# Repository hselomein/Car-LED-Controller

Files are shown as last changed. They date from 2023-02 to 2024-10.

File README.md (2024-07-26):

# Car-LED-Controller

Credits:
  - Corey Davis created the project and put together the prototypes.
  - Yves Avady wrote the code for this project.

This project controls an addressable LED Strip and LED matrix using the light inputs from a car electrical system.

With this project, we are taking an esp32 microcontroller and making an LED controller for the strip. 
The LED strip is a 12v WS2811 with 120 LEDs per meter

LED Strip Actions:
- Startup is a night rider style sweep 3 times until it is a solid white bar
- DRL Modes will control the LED strip brightness.

-  When DRLs are in Daytime Running Light Mode strip will be at full brightness
-  When DRLs are used as parking lights, the strip will be dimmed to a lower brightness
  
- Horn usage makes the lights turn dark amber to represent "Angry Mode"
- Indicators will show using a single chasing pattern that stays on for as long as the voltage is applied. This is to match the blink of the indicator circuit
- When hazard lights are on there will be a chasing pattern starting from the middle and ending at the ends
- There will be a button to cycle between Normal, Uber, and Lyft Modes
- Uber Mode, the led strip will be a Seafoam Greem color
- LYFT Mode, the led strip will be Magenta
There will be a physical switch installed to disable the light for law enforcement and/or vehicle inspection purposes

There are 5 voltage reading inputs 

  - DRL Left Sensing, 
  - DRL right Sensing,
  - Horn Sensing,
  - Left Indicator,
  - Right Indicator

At powerup LED strip will sweep 3 times each pass leaving the light on brighter until filled.
It'll stay filled white unless another mode is selected or an action happens

2 LED Matrices will be attached to the front and back of the vehicle and show 1 of 3 screens
  - Off or Blank for normal driving mode
  - Uber Mode: Shows Uber logo
  - Lyft Mode: Shows Lyft Logo

Actions:
DRL is in DRL Mode light will be at full brightness
DRL is in parking light mode and will be at half-brightness
When not in Uber or Lyft mode, the LED Matrix will be blank or off
Horn is pressed LED Strip will turn orange for the duration of the press
UBER Mode will turn the lights Cyan and the LED Matrix will show the Uber logo
Lyft Mide will turn the lights Magenta and the LED Matrix will show the Lyft Logo
Angry Mode will be some orangy red color, cant be RED as that is illegal in the front
The left indicator will show a chasing pattern, starting in the center and moving to the left side of the strip
The right indicator will show a chasing pattern, starting in the center and moving to the right side of the strip
Vehicle inspection mode, which will disable the lights, physical switch

There is a parts list so you can build this as well.

How to use with Platform-io IDE:
- You will need the Platformio-ide extension installed in VSCODE to compile the code
The src folder is where the code you want to compile and upload code to the ESP32
The main program code is in the file "main.cpp".

How to use with Arduino IDE
- The Arduino project files are located in the ArduinoIDE folder. This part is not complete still porting the code

This program is modular. You can enable or disable specific features by setting directives to true or false.

Build Configuration Options - This program is modular in the sense that you can have everything (LED Strip, LED Matrix) work or just cartain parts.  
See the Build Configuration Options to enable or disable certain features.

Examples:  
//Build Configuration Options  
  #define DEBUG false       //Enable serial output for debug, change to "false" to disable  
  #define SCREENTEST false  //To enable the boot up screen test, change to "true", to disable change to "false"  
  #define LED_MATRIX true   //Set to "true" if you want to use a 64x64 LED Matrix, "false" to disable  
  #define LED_STRIP true    //Set to "true" if you want to use the led strip, "false" to disable  
  #define NUM_MODES 2       //How many modes will the mode button handle (2 for Uber and Lyft signs)  

Code Notes:
- Car_LED_Controller-LED_Matrix_64x64.ino - this is the program for the 64x64 P2 LED Matrix for the Arduino ide, this still needs to be completed
- Part List - this is the shopping list of parts for this project

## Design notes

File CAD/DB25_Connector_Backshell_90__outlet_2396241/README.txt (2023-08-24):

DB25 Connector Backshell 90° outlet by PeterBrit on Thingiverse: https://www.thingiverse.com/thing:2396241

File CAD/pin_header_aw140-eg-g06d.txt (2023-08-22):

"Symbol";"Value";"Unit";
"TraceParts.PartNumber";"10-15062010-090510";"";
"REFERENCE";"AW140-EG-G06D";"";
"TraceParts.PartTitle";"Pin header, pitch 2.54mm, straight, single row, 6 contacts, plating : Gold flash, pin length = 11,2mm ( A=5,66; B=3,00)";"";
"TraceParts.InstanceId";"10-15062010-0905107AUE0LFKUDNPOKZ3LGYJF4ZHA";"";
"SUPPLIER";"ASSMANN WSW components";"";
"DESIGN";"Pin header, pitch 2.54mm, straight, single row, 6 contacts, plating : Gold flash, pin length = 11,2mm ( A=5,66; B=3,00)";"";
"TraceParts.PartVersion";"1.2.7";"";
"TraceParts.PartLanguage";"en";"";

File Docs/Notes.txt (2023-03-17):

Arduino LED Controller

Power: 0v - 15v 
What it powers, Arduino, 3x 5v buck converters, 1 white 60" led strip  
Input1: 1 voltage divier circuit that divides automotive level voltage 11 times: 1-1Mohm and 1-100kohm resistors
Expected input ranges: 0v to 15v
Expected divided voltage: 0v ,12v = 1.091v ,15v = 1.364v
Input2: 1 voltage divier circuit that divides automotive level voltage 11 times: 1-1Mohm and 1-100kohm resistors
Expected input ranges: 0v to 15v
Expected divided voltage: 0v ,12v = 1.091v ,15v = 1.364v

voltage divider
DRL -> 1M -> sense pin -> 47k -> ground

 pseudo code
Buf = 1 //+-1v
Div = 50 / 1000 //divider value
LBL = 2 //2v low beam
DRL = 12 //12v DRL 
Brightness = in / Div
If abs(brightness - LBL) < Buf then lowBeam=true
Also, to set led brightness
LEDv = brightness * 256 / 12
If LEDv > 256 then LEDv =256
If LEDv < 0 then LEDv =0c ch

Arduino setup
Pins to device mapping
D2 => In1 Relay
D3 => In2 Relay
A2 => DRL Sense
A3 => PK_L Sense
A4 => Hn Sense
A5 => HiBm Sense
# of LEDs in strip 30 effective 90 individual pixels, WS2811 controller 

ESP32 Notes:
https://www.electronicshub.org/esp32-pinout/

Pins required:
4 analog pins for input
1 ditigal pin for input
8 digital pins for output
2 power pins

Reserved pins:
2-4 input only pins
12 bootstrap pin
14-17 power and ground
27,28 uart0 rx/tx 
6-11 do not use on 36 or 38 pin verson, in use for flash,  - these are not exposed on pu 30pin version
33, 39 connected to hall sensor

Planned pinout:
2 DRL Sense GPIO36
3 PK_L Sense GPIO39
4 Hn Sense GPIO34
5 HiBm Sense GPIO35

21 LCD Data (SDA)
22 LCD Clock (SCL)

27 Relay1
14 Relay2

30 Mode Selection Button Output GPIO23
29 Reserved
26 LED Strip DAta GPIO21

HArdware List
ESP32-WROOM-32
bidrectional logic level converter
20A Buck converter
40in led strip

Car Tested Voltages
Car Off, DRL in parking light mode on : 1.9v
Car On, DRL in parking light mode on : 2.0v
Car on, DRL mode on : 14.8v

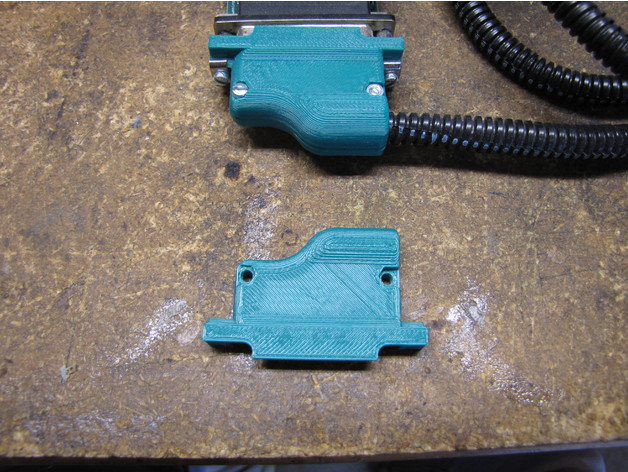
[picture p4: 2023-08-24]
CAD/DB25_Connector_Backshell_90__outlet_2396241/images/e1f9b99bbdfb767f7688bc1128a824b8.JPG

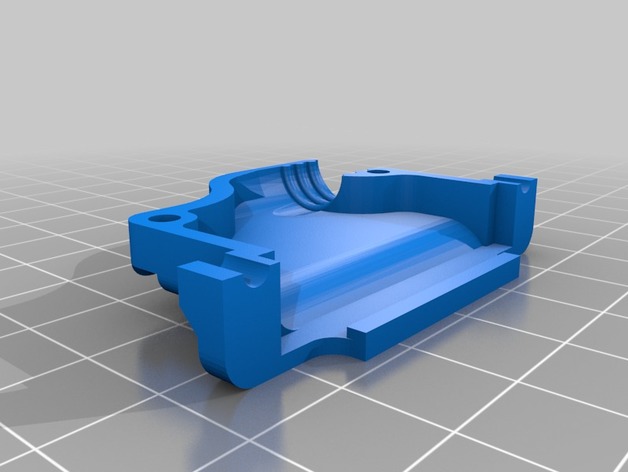
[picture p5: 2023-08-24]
CAD/DB25_Connector_Backshell_90__outlet_2396241/images/DB25_backshell_a.jpg

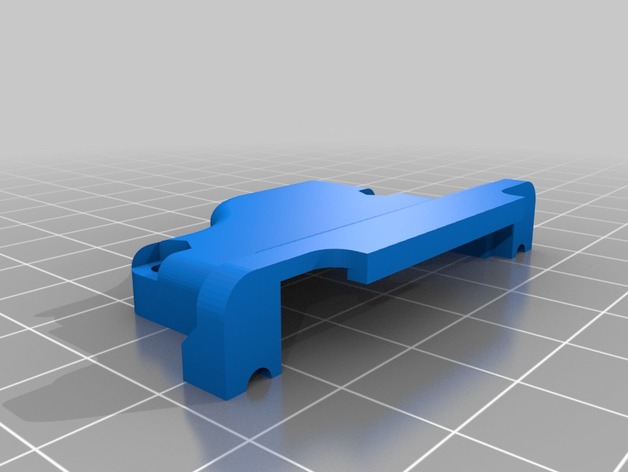
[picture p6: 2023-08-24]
CAD/DB25_Connector_Backshell_90__outlet_2396241/images/DB25_backshell_b.jpg

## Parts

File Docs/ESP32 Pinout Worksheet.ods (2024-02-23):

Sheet: ESP32-WROOM-32_30PIN
Label | GPIO | Safe to use? | Reason | Device Assigned | Need to assign to alternate location | Notes
D0 | 0 | Caution | must be HIGH during boot and LOW for programming
TX0 | 1 | Not Recondmended | Tx pin, used for flashing and debugging
D2 | 2 | Caution | must be LOW during boot and also connected to the on-board LED | LED Strip
RX0 | 3 | Not Recondmended | Rx pin, used for flashing and debugging
D4 | 4 | Yes |  | LED Matrix
D5 | 5 | Caution | must be HIGH during boot | LED Matrix
D12 | 12 | Caution | must be LOW during boot | LED Matrix
D13 | 13 | Yes |  | LED Matrix
D14 | 14 | Yes |  | LED Matrix
D15 | 15 | Caution | must be HIGH during boot, prevents startup log if pulled LOW | LED Matrix
RX2 | 16 | Yes |  | LED Matrix
TX2 | 17 | Yes |  | LED Matrix
D18 | 18 | Yes |  | Relay
D19 | 19 | Yes |  | Relay
D21 | 21 | Yes |  | Character LCD
D22 | 22 | Yes |  | LED Matrix |  | To declare other pins for i2c communication, add this to the code in the setup, Wire.begin(I2C_SDA, I2C_SCL); https://microcontrollerslab.com/esp32-i2c-communication-tutorial-arduino-ide/
D23 | 23 | Yes |  | LED Matrix
D25 | 25 | Yes |  | LED Matrix
D26 | 26 | Yes |  | LED Matrix
D27 | 27 | Yes |  | LED Matrix
D32 | 32 | Yes |  | LED Matrix
D33 | 33 | Yes |  | Character LCD
D34 | 34 | Caution | Input only GPIO, cannot be configured as output, No Internal pull up /down resistors | DRL Sense
D35 | 35 | Caution | Input only GPIO, cannot be configured as output, No Internal pull up /down resistors | Horn Sense
VP | 36 | Caution | Input only GPIO, cannot be configured as output, No Internal pull up /down resistors | Select Button
VN | 39 | Caution | Input only GPIO, cannot be configured as output, No Internal pull up /down resistors | Reserved Sense

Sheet: ESP32-WROOM-32_38PIN
LABEL | GPIO | Input | Output | Notes | Device Assigned | Assinged in CODE | Notes
1 | 3v3 | X | X | 3.3v Power in
2 | EN | X | X | Reset Button
3 | 36 | OK |  | input only | HORN Sense | HORN_PIN | ADC1_CH0
4 | 39 | OK |  | input only | DRL Sense | DRL_PIN | ADC1_CH3
5 | 34 | OK |  |  | Mode Button | ezButton
6 | 35 | OK |  |  | LED Strip | LED_PIN
7 | 32 | OK | OK |  | LED Matrix | E_PIN
8 | 33 | OK | OK |  | LED Matrix | B1_PIN
9 | 25 | OK | OK |  | LED Matrix | R1_PIN
10 | 26 | OK | OK |  | LED Matrix | G1_PIN
11 | 27 | OK | OK |  | LED Matrix | A_PIN
12 | 14 | OK | OK | outputs PWM signal at boot | LED Matrix | R2_PIM
13 | 12 | OK | OK |  | LED Matrix | G2_PIN
14 | GND | X | X | Ground
15 | 13 | OK | OK | outputs PWM signal at boot | LED Matrix | B2_PIN
16 | 9 | X | X | connected to the integrated SPI flash
17 | 10 | X | X | connected to the integrated SPI flash
18 | 11 | X | X | connected to the integrated SPI flash
19 | VIN 5v |  |  | 5v Power in
20 | 6 | X | X | connected to the integrated SPI flash
21 | 7 | X | X | connected to the integrated SPI flash
22 | 8 | X | X | connected to the integrated SPI flash
23 | 15 | OK | OK |  | LED Matrix | OE_PIN
24 | 2 | OK | OK | connected to on-board LED | LED Matrix | B_PIN
25 | 0 | pulled up | OK | outputs PWM signal at boot
26 | 4 | OK | OK |  | LED Matrix | LAT_PIN
27 | 16 | OK | OK |  | LED Matrix | CLK_PIN
28 | 17 | OK | OK |  | LED Matrix | D_PIN
29 | 5 | OK | OK | outputs PWM signal at boot | LED Matrix | C_PIN
30 | 18 | OK | OK |  | Relay | RELAY_PIN_1
31 | 19 | OK | OK |  | Relay | RELAY_PIN_2
32 | GND |  |  | Ground
33 | 21 | OK | OK |  | LCD Character Display
34 | 3 | OK | RX Pin | HIGH at boot
35 | 1 | TX Pin | OK | debug output at boot
36 | 22 | OK | OK |  | LCD Character Display
37 | 23 | OK | OK
38 | GND |  |  | Ground
 | 20 | OK | OK
 | 24 | OK | OK
 | 28 | OK | OK
 | 29 | OK | OK
 | 30 | OK | OK
 | 31 | OK | OK
 | 37 | OK |  | input only
 | 38 | OK |  | input only

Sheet: DB25_Connector
Front LED Matrix |  |  |  | Rear LED Matrix
Pin | Purpose | Assigned in CODE | Input / Output | Pin | Purpose | Assigned in CODE | Input / Output
1 | LED MATRIX | R1_PIN | Output | 1 | LED MATRIX | R1_PIN | Output
2 | LED MATRIX | G1_PIN | Output | 2 | LED MATRIX | G1_PIN | Output
3 | LED MATRIX | B1_PIN | Output | 3 | LED MATRIX | B1_PIN | Output
4 | LED MATRIX | R2_PIM | Output | 4 | LED MATRIX | R2_PIM | Output
5 | LED MATRIX | G2_PIN | Output | 5 | LED MATRIX | G2_PIN | Output
6 | LED MATRIX | B2_PIN | Output | 6 | LED MATRIX | B2_PIN | Output
7 | LED MATRIX | E_PIN | Output | 7 | LED MATRIX | E_PIN | Output
8 | LED MATRIX | A_PIN | Output | 8 | LED MATRIX | A_PIN | Output
9 | LED MATRIX | B_PIN | Output | 9 | LED MATRIX | B_PIN | Output
10 | LED MATRIX | C_PIN | Output | 10 | LED MATRIX | C_PIN | Output
11 | LED MATRIX | D_PIN | Output | 11 | LED MATRIX | D_PIN | Output
12 | LED MATRIX | CLK_PIN | Output | 12 | LED MATRIX | CLK_PIN | Output
13 | LED MATRIX | LAT_PIN | Output | 13 | LED MATRIX | LAT_PIN | Output
14 | LED MATRIX | OE_PIN | Output | 14 | LED MATRIX | OE_PIN | Output
15 | LED MATRIX | GND | Output | 15 | LED MATRIX | GND | Output
16 | LED MATRIX | GND | Output | 16 | LED MATRIX | GND | Output
17 | Relay | Relay | Input | 17
18 | Horn Signal | Hn | Input | 18
19 | DRL Signal | DRL | Input | 19
20 | Power | "+5V" | Output | 20
21 | Power | "+5V" | Output | 21
22 | Power | GND | Input | 22 | Power | GND | Input
23 | Power | GND | Input | 23 | Power | GND | Input
24 | Power | "+5V" | Input | 24 | Power | "+5V" | Input
25 | Power | "+5V" | Input | 25 | Power | "+5V" | Input

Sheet: Working_LED_Matrix_Pinouts
Working LED Matrix Pinouts
Pin Label | ESP32 Pinouts
 | PCB V9 | PCB | Waveshare
R1_PIN | 25 | 32 | 25
G1_PIN | 26 | 33 | 26
B1_PIN | 33 | 25 | 27
R2_PIN | 14 | 26 | 14
G2_PIN | 12 | 27 | 12
B2_PIN | 13 | 14 | 13
A_PIN | 27 | 13 | 23
B_PIN | 2 | 15 | 22
C_PIN | 5 | 2 | 5
D_PIN | 17 | 4 | 17
E_PIN | 32 | 12 | 32
LAT_PIN | 4 | 17 | 4
OE_PIN | 15 | 5 | 15
CLK_PIN | 16 | 16 | 16

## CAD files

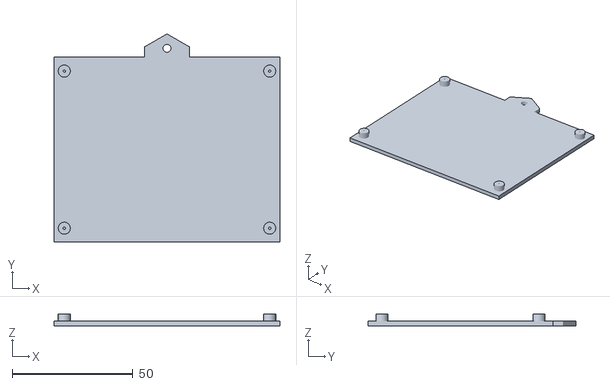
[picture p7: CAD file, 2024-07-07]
CAD/Front LED Matrix Control Box-Matrix HolderDoor Assembly.stl
93.5 x 86.1 x 5.00

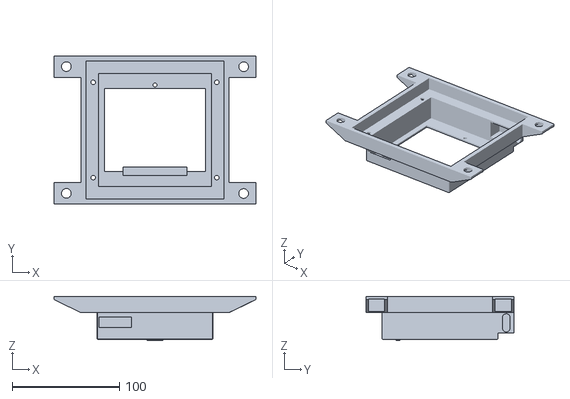
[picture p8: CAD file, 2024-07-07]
CAD/Front LED Matrix Control Box-Matrix HolderMatrix Assembly.stl
188.0 x 138.0 x 41.1

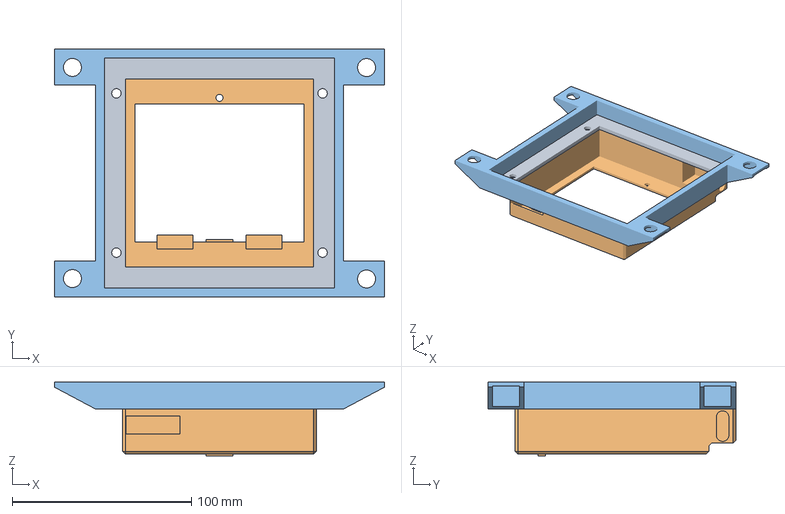
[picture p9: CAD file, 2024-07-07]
CAD/Front LED Matrix Control Box-Matrix HolderMatrix Holder Assembly.3mf
184.0 x 138.0 x 41.0 mm

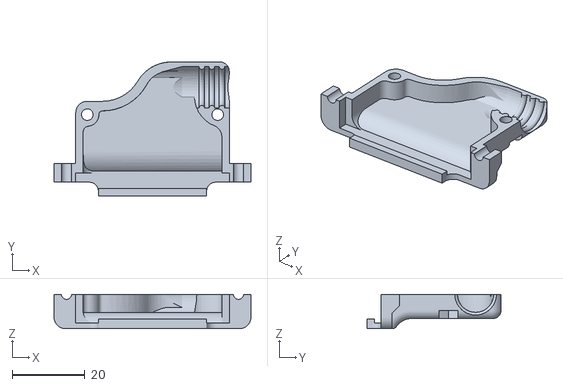
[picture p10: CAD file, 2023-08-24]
CAD/DB25_Connector_Backshell_90__outlet_2396241/files/DB25_backshell_a.STL
54.1 x 36.8 x 9.47

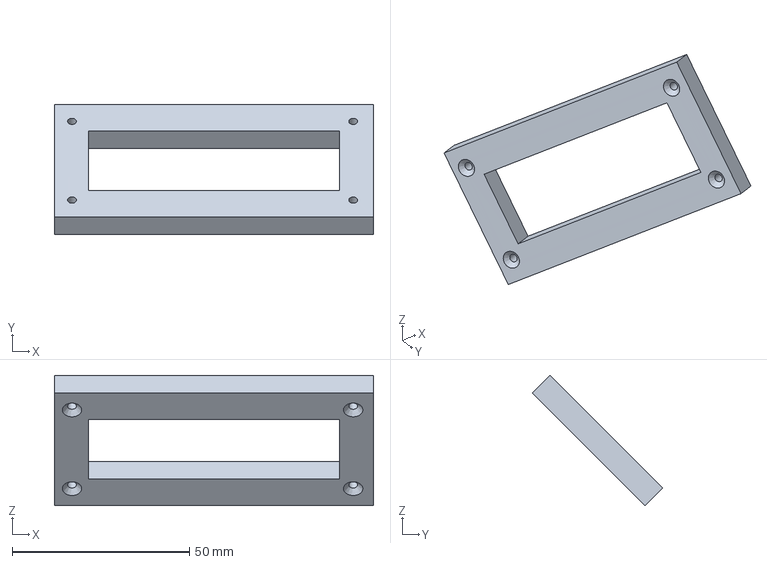
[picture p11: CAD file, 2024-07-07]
CAD/Corey's Rear Enclosure2-LCD Cover.3mf
90.0 x 36.8 x 36.8 mm

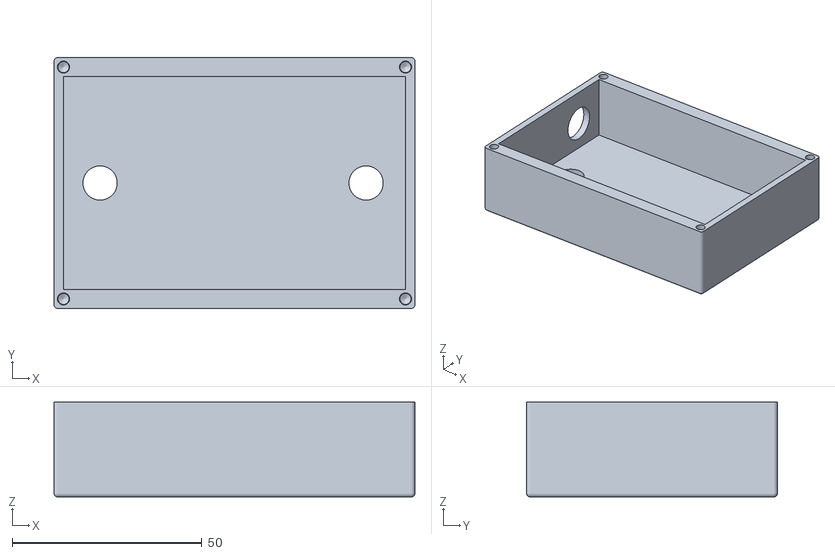
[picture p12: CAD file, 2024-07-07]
CAD/Front LED Matrix Control Box-LCD DisplayBottom Body.stl
95.0 x 66.0 x 25.0

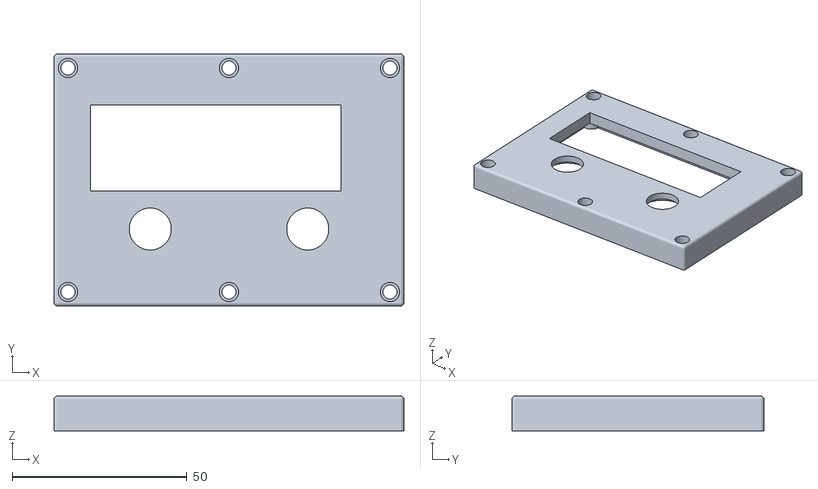
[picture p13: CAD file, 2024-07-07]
CAD/Front LED Matrix Control Box-LCD DisplayLid.stl
100.0 x 72.0 x 10.0

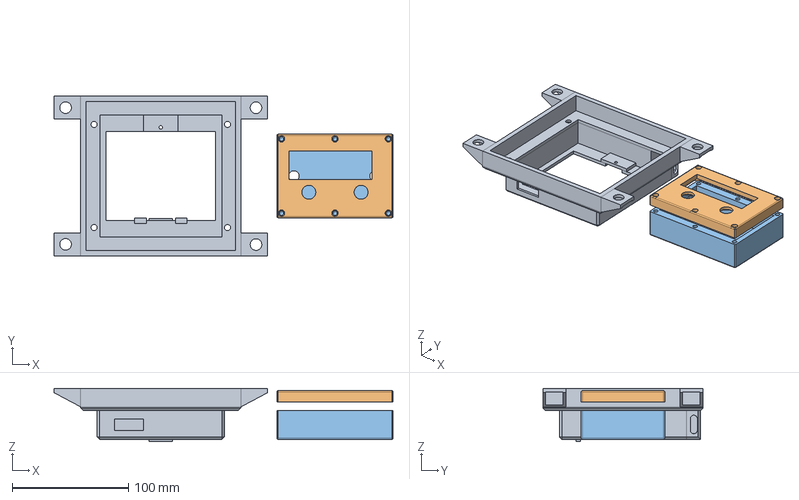
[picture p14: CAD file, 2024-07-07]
CAD/Front LED Matrix Control Box.FCStd
292.0 x 138.0 x 46.0 mm
Complete Assembly
Lid
Button Body

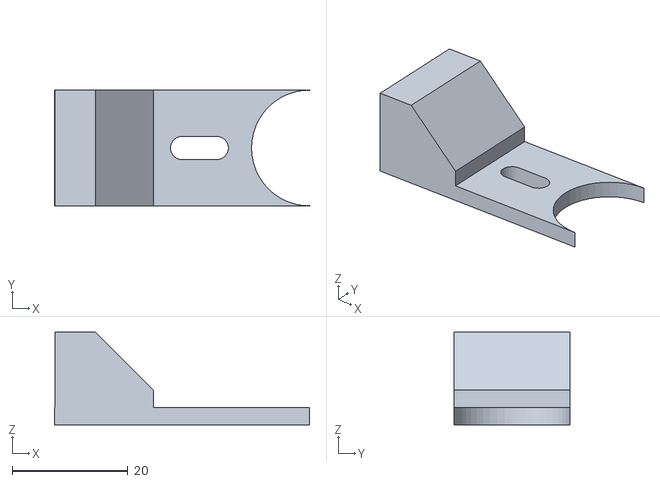
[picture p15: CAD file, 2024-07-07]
CAD/Ender_5_Plus_BL_Touch_Stop_shortened.stl
44.0 x 20.0 x 16.0

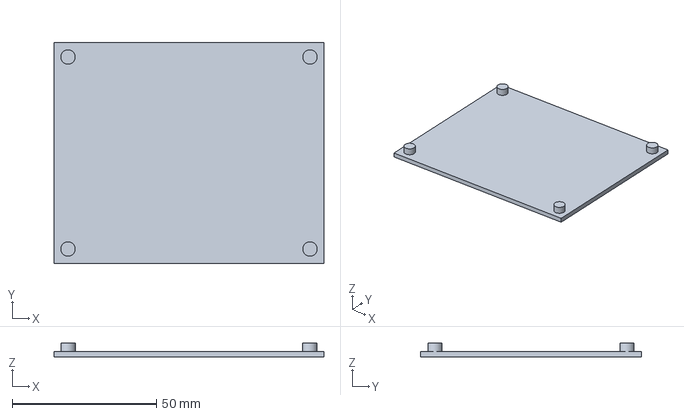
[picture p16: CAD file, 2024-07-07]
CAD/Front LED Matrix Control Box Door.3mf
93.5 x 76.5 x 5.00 mm

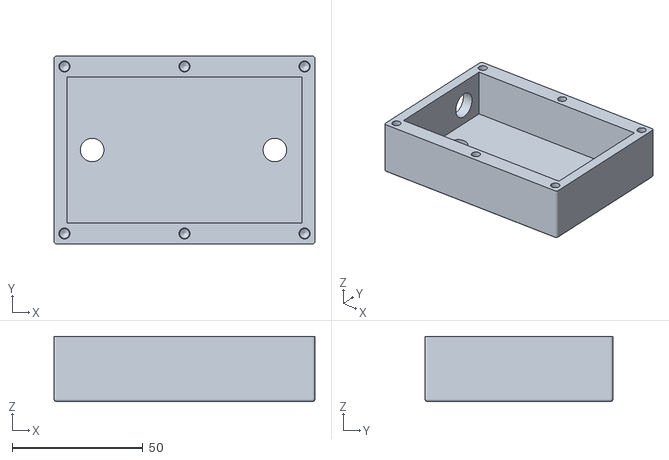
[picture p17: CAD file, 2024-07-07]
CAD/Front LED Matrix Control Box-LCD DisplayButton Body.stl
100.0 x 72.0 x 25.0

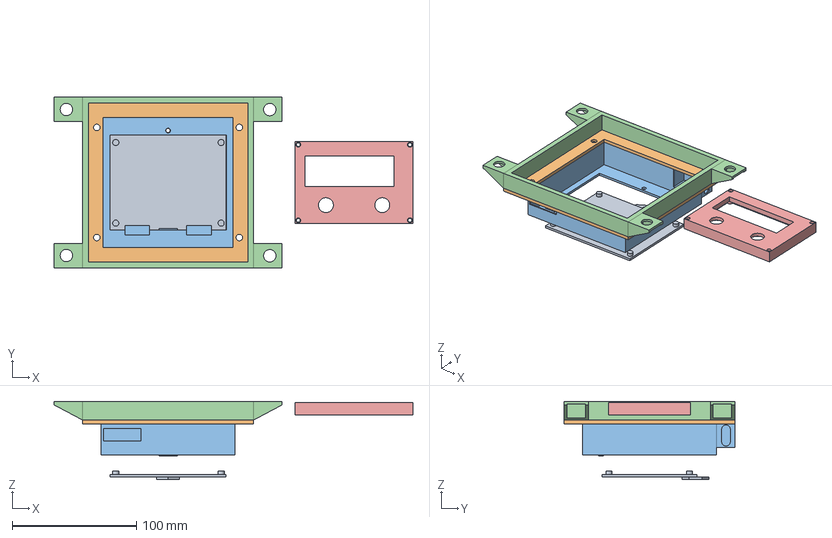
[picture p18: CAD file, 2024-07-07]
CAD/Front LED Matrix Control Box1.FCStd
289.5 x 138.0 x 63.0 mm
Door
Matrix Backplane
Control Board Box
Matrix Frame
Lid

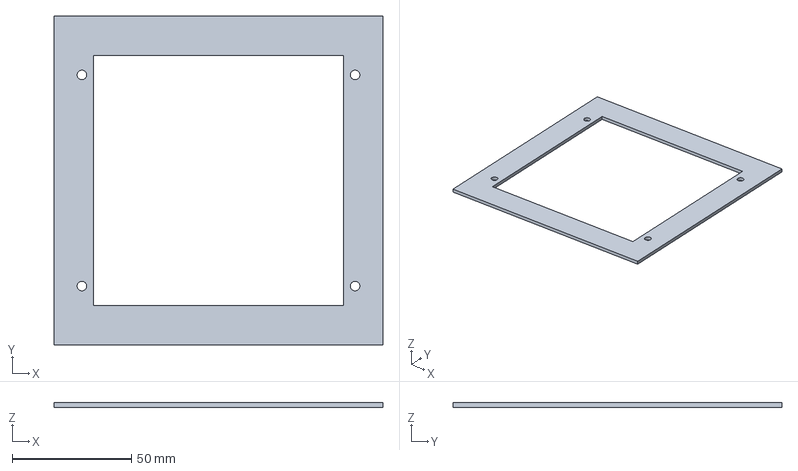
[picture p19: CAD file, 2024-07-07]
CAD/Front LED Matrix Control Box-PartPad.3mf
138.0 x 138.0 x 2.00 mm

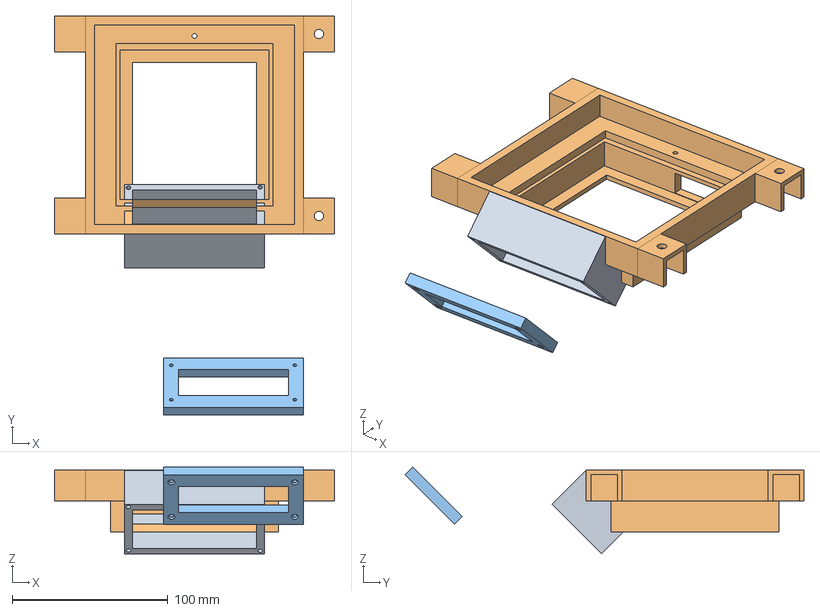
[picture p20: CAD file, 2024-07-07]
CAD/Corey's Rear Enclosure2.FCStd
180.0 x 256.4 x 55.7 mm
Slice

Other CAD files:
CAD/DB25_Connector_Backshell_90__outlet_2396241/files/DB25_backshell_b.STL
CAD/Corey's Rear Enclosure2-Body.stl
CAD/Controller Enclosure v1-Control Board.dxf
CAD/Corey's Rear Enclosure2-Door.stl
CAD/B2B-XH-A.step
CAD/B4B-XH-A.step
CAD/B6B-XH-A.step
CAD/BOB-12009--3DModel-STEP-1.STEP
CAD/BOB-12009.step
CAD/Controller Enclosure v1-64x64 LED Matrix.stl
CAD/Controller Enclosure v1.FCStd
CAD/Corey's Rear Enclosure-Body.stl
CAD/Corey's Rear Enclosure-Lid.stl
CAD/Corey's Rear Enclosure.20231113-090606.FCStd
CAD/Corey's Rear Enclosure.3mf
CAD/Corey's Rear Enclosure.FCStd
CAD/Corey's Rear Enclosure.Orig.FCStd
CAD/Corey's Rear Enclosure.stl
CAD/Corey's Rear Enclosure2-LCD Cover.stl
CAD/Corey's Rear Enclosure2.stl
CAD/DB25S564GTLF--3DModel-STEP-56544.STEP
CAD/Front LED Matrix Control Box-Matrix HolderMatrix Holder Assembly.stl
CAD/GreenyBig.step
CAD/GreenyMedium.step
CAD/GreenySmall.step
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

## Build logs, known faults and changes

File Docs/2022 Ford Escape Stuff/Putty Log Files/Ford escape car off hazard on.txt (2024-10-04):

F0 54 01 1F 38 FF 93 00 55 30 00 55 01 21 F0 84 00 28 40 2F 9F BD 00 55 40 00 00 00 FF FF FF FF FF 5F 00 55 00 21 E0 54 01 1F 38 FF FF 47 00 55 70 00 00 00 FF FF FF FF FF 8F 00 55 01 21 F0 84 00 28 40 2F 9F BD 00 55 C0 00 55 00 21 F0 54 01 1F 38 FF FF 47 00 55 30 00 55 01 21 F0 84 00 28 40 2F 9F BD 00 55 40 00 00 00 FF FF FF FF FF 5F 00 55 00 21 F0 54 01 1F 38 FF FF 47 00 55 70 00 00 00 FF FF FF FF FF 8F 00 55 01 21 E0 84 00 28 40 2F 9F BD 00 55 C0 00 55 00 21 E0 54 01 1F 38 FF FF 47 00 55 30 00 55 01 21 E0 84 00 28 40 2F BF BD 00 55 40 00 00 00 FF FF FF FF FF 9F 00 55 00 21 F0 54 01 1F 38 FF FF 47 00 55 70 00 00 00 FF FF FF FF FF 8F 00 55 01 21 F0 84 00 28 40 2F 9F BD 00 55 C0 00 55 00 21 F0 54 01 1F 38 FF FF 47 00 55 30 00 55 01 21 F0 84 00 28 40 2F 9F BD 00 55 40 00 00 00 FF FF FF FF FF 5F 00 55 00 21 E0 54 01 3F 38 FF FF 47 00 55 70 00 00 00 FF FF FF FF FF 8F 00 55 01 21 F0 84 00 28 40 2F 9F BD 00 55 C0 00 55 00 21 F0 54 01 1F 38 FF FF 47 00 55 30 00 55 01 21 E0 84 00 28 40 2F 9F BD 00 55 40 00 00 00 FF FF FF FF FF 9F 00 55 00 21 E0 54 01 1F 38 FF FF 47 00 55 70 00 00 00 FF FF FF FF FF 8F 00 55 01 21 E0 84 00 28 40 2F 9F BD 00 55 C0 00 55 00 21 F0 54 01 1F 38 FF FF 47 00 55 30 00 55 01 21 F0 84 00 28 40 2F 9F BD 00 55 40 00 00 00 FF FF FF FF FF 5F 00 55 00 21 F0 54 01 1F 38 FF FF 47 00 55 70 00 00 00 FF FF FF FF FF 8F 00 55 01 21 F0 84 00 28 40 2F 9F BD 00 55 C0 00 55 00 21 E0 54 01 1F 38 FF FF 47 00 55 30 00 55 01 21 F0 84 00 28 40 2F 9F BD 00 55 40 00 00 00 FF FF FF FF FF 9F 00 55 00 21 F0 54 01 1F 38 FF FF 47 00 55 70 00 00 00 FF FF FF FF FF 8F 00 55 01 21 E0 84 00 28 40 2F 9F BD 00 55 C0 00 55 00 21 F0 54 01 1F 38 FF FF 47 00 55 30 00 55 01 21 F0 84 00 28 40 2F 9F BD 00 55 40 00 00 00 FF FF FF FF FF 9F 00 55 00 21 F0 54 01 1F 38 FF FF 47 00 55 E0 00 00 00 FF FF FF FF FF 8F 00 55 01 21 F0 84 00 28 40 2F 9F BD 00 55 C0 00 55 00 21 F0 54 01 3F 38 FF FF 47 00 55 30 00 55 01 21 E0 84 00 28 40 2F 9F BD 00 55 40 00 00 00 FF FF FF FF FF 9F 00 55 00 21 F0 54 01 1F 38 FF FF 47 00 55 70 00 00 00 FF FF FF FF FF 8F 00 55 01 21 E0 84 00 28 40 2F 9F BD 00 55 C0 00 55 00 21 F0 54 01 1F 38 FF FF 47 00 55 30 00 55 01 21 E0 84 00 28 40 2F 9F BD 00 55 40 00 00 00 FF FF FF FF FF 9F 00 55 00 21 E0 54 01 1F 38 FF FF 47 00 55 70 00 00 00 FF FF FF FF FF 8F 00 55 01 21 F0 84 00 28 40 2F 9F BD 00 55 C0 00 55 00 21 F0 54 01 1F 38 FF FF 47 00 55 30 00 55 01 21 F0 84 00 28 40 2F 9F BD 00 55 40 00 00 00 FF FF FF FF FF 9F 00 55 00 21 F0 54 01 1F 38 FF FF 47 00 55 70 00 00 00 FF FF FF FF FF 8F 00 55 01 21 E0 84 00 28 40 2F 9F BD 00 55 C0 00 55 00 21 F0 54 01 1F 38 FF FF 47 00 55 30 00 55 01 21 F0 84 00 28 40 2F 9F BD 00 55 40 00 00 00 FF FF FF FF FF 9F 00 55 00 21 F0 54 01 1F 38 FF FF 47 00 55 70 00 00 00 FF FF FF FF FF 8F 00 55 01 21 F0 84 00 28 40 2F 9F BD 00 55 C0 00 55 00 21 F0 54 01 1F 38 FF FF 47 00 55 30 00 55 01 21 F0 84 00 28 40 2F 9F BD 00 55 40 00 00 00 FF FF FF FF FF 5F 00 55 00 21 F0 54 01 3F 38 FF FF 47 00 55 70 00 00 00 FF FF FF FF FF 8F 00 55 01 21 F0 84 00 28 40 2F 9F BD 00 55 C0 00 55 00 21 F0 54 01 1F 38 FF FF 47 00 55 30 00 55 01 21 F0 84 00 28 40 2F 9F BD 00 55 40 00 00 00 FF FF FF FF FF 9F 00 55 00 21 F0 54 01 1F 38 FF FF 47 00 55 70 00 00 00 FF FF FF FF FF 8F 00 55 01 21 F0 84 00 28 40 2F 9F BD 00 55 C0 00 55 00 21 F0 54 01 1F 38 FF FF 47 00 55 30 00 55 01 21 F0 84 00 28 40 2F 9F BD 00 55 40 00 00 00 FF FF FF FF FF 9F 00 55 00 21 F0 54 01 3F 38 FF FF 47 00 55 70 00 00 00 FF FF FF FF FF 8F 00 55 01 21 F0 84 00 28 40 2F BF BD 00 55 C0 00 55 00 21 F0 54 01 1F 38 FF FF 47 00 55 30 00 55 01 21 E0 84 00 28 40 2F BF BD 00 55 40 00 00 00 FF FF FF FF FF 5F 00 55 00 21 E0 54 01 1F 38 FF FF 47 00 55 E0 00 00 00 FF FF FF FF FF 8F 00 55 01 21 F0 84 00 28 40 2F 9F BD 00 55 C0 00 55 00 21 F0 54 01 3F 38 FF FF 47 00 55 30 00 55 01 21 F0 84 00 28 40 2F 9F BD 00 55 40 00 00 00 FF FF FF FF FF 9F 00 55 00 21 E0 54 01 1F 38 FF FF 47 00 55 70 00 00 00 FF FF FF FF FF 8F 00 55 01 21 F0 84 00 28 40 2F 9F BD 00 55 C0 00 55 00 21 F0 54 01 1F 38 FF FF 47 00 55 30 00 55 01 21 F0 84 00 28 40 2F 9F BD 00 55 40 00 00 00 FF FF FF FF FF 9F 00 55 00 21 F0 54 01 1F 38 FF FF 47 00 55 E0 00 00 00 FF FF FF FF FF 8F 00 55 01 21 F0 84 00 28 40 2F 9F BD 00 55 C0 00 55 00 21 F0 54 01 1F 38 FF FF 47 00 55 20 00 55 01 21 F0 84 00 28 40 2F 9F BD 00 55 40 00 00 00 FF FF FF FF FF 9F 00 55 00 21 F0 54 01 3F 38 FF FF 47 00 55 E0 00 00 00 FF FF FF FF FF 8F 00 55 01 21 E0 84 00 28 40 2F 9F BD 00 55 C0 00 55 00 21 F0 54 01 1F 38 FF FF 47 00 55 20 00 55 01 21 F0 84 00 28 40 2F 9F BD 00 55 40 00 00 00 FF FF FF FF FF 9F 00 55 00 21 F0 54 01 1F 38 FF FF 47 00 55 70 00 00 00 FF FF FF FF FF 8F 00 55 01 21 E0 84 00 28 40 2F BF BD 00 55 C0 00 55 00 21 F0 54 01 1F 38 FF FF 47 00 55 20 00 55 01 21 E0 84 00 28 40 2F 9F BD 00 55 40 00 00 00 FF FF FF FF FF 9F 00 55 00 21 F0 54 01 1F 38 FF FF 47 00 55 70 00 00 00 FF FF FF FF FF 8F 00 55 01 21 F0 84 00 28 40 2F 9F BD 00 55 C0 00 55 00 21 E0 54 01 1F 38 FF FF 47 00 55 20 00 55 01 21 F0 84 00 28 40 2F 9F BD 00 55 40 00 00 00 FF FF FF FF FF 5F 00 55 00 21 F0 54 01 1F 38 FF FF 47 00 55 E0 00 00 00 FF FF FF FF FF 8F 00 55 01 21 F0 84 00 28 40 2F 9F BD 00 55 C0 00 55 00 21 F0 54 01 1F 38 FF FF 47 00 55 30 00 55 01 21 E0 84 00 28 40 2F BF BD 00 55 40 00 00 00 FF FF FF FF FF 9F 00 55 00 21 E0 54 01 1F 38 FF FF 47 00 55 E0 00 00 00 FF FF FF FF FF 8F 00 55 01 21 F0 84 00 28 40 2F 9F BD 00 55 C0 00 55 00 21 F0 54 01 1F 38 FF FF 47 00 55 30 00 55 01 21 E0 84 00 28 40 2F BF BD 00 55 40 00 00 00 FF FF FF FF FF 9F 00 55 00 21 F0 54 01 1F 38 FF FF 47 00 55 70 00 00 00 FF FF FF FF FF 8F 00 55 01 21 E0 84 00 28 40 2F BF BD 00 55 C0 00 55 00 21 F0 54 01 1F 38 FF FF 47 00 55 30 00 55 01 21 F0 84 00 28 40 2F 9F BD 00 55 40 00 00 00 FF FF FF FF FF 5F 00 55 00 21 F0 54 01 1F 38 FF FF 47 00 55 70 00 00 00 FF FF FF FF FF 8F 00 55 01 21 E0 84 00 28 40 2F 9F BD 00 55 C0 00 55 00 21 E0 54 01 1F 38 FF FF 47 00 55 20 00 55 01 21 E0 84 00 28 40 2F BF BD 00 55 40 00 00 00 FF FF FF FF FF 9F 00 55 00 21 F0 54 01 1F 38 FF FF 47 00 55 70 00 00 00 FF FF FF FF FF 8F 00 55 01 21 E0 84 00 28 40 2F 9F BD 00 55 C0 00 55 00 21 E0 54 01 3F 38 FF FF 47 00 55 30 00 55 01 21 E0 84 00 28 40 2F 9F BD 00 55 40 00 00 00 FF FF FF FF FF 9F 00 55 00 21 F0 54 01 1F 38 FF FF 47 00 55 E0 00 00 00 FF FF FF FF FF 8F 00 55 01 21 E0 84 00 28 40 2F 9F BD 00 55 C0 00 55 00 21 F0 54 01 1F 38 FF FF 47 00 55 30 00 55 01 21 F0 84 00 28 40 2F BF BD 00 55 40 00 00 00 FF FF FF FF FF 9F 00 55 00 21 E0 54 01 1F 38 FF FF 47 00 55 E0 00 00 00 FF FF FF FF FF 8F 00 55 01 21 E0 84 00 28 40 2F 9F BD 00 55 C0 00 55 00 21 F0 54 01 3F 38 FF FF 47 00 55 20 00 55 01 21 E0 84 00 28 40 2F 9F BD 00 55 40 00 00 00 FF FF FF FF FF 9F 00 55 00 21 E0 54 01 1F 38 FF FF 47 00 55 E0 00 00 00 FF FF FF FF FF 8F 00 55 01 21 F0 84 00 28 40 2F BF BD 00 55 C0 00 55 00 21 E0 54 01 1F 38 FF FF 47 00 55 20 00 55 01 21 E0 84 00 28 40 2F 9F BD 00 55 40 00 00 00 FF FF FF FF FF 9F 00 55 00 21 F0 54 01 3F 38 FF FF 47 00 55 70 00 00 00 FF FF FF FF FF 8F 00 55 01 21 E0 84 00 28 40 2F 9F BD 00 55 C0 00 55 00 21 F0 54 01 1F 38 FF FF 47 00 55 30 00 55 01 21 E0 84 00 28 40 2F 9F BD 00 55 40 00 00 00 FF FF FF FF FF 9F 00 55 00 21 E0 54 01 1F 38 FF FF 47 00 55 70 00 00 00 FF FF FF FF FF 8F 00 55 01 21 F0 84 00 28 40 2F BF BD 00 55 C0 00 55 00 21 F0 54 01 1F 38 FF FF 47 00 55 30 00 55 01 21 F0 84 00 28 40 2F BF BD 00 55 40 00 00 00 FF FF FF FF FF 9F 00 55 00 21 E0 54 01 1F 38 FF FF 47 00 55 70 00 00 00 FF FF FF FF FF 8F 00 55 01 21 E0 84 00 28 40 2F 9F BD 00 55 C0 00 55 00 21 E0 54 01 1F 38 FF FF 47 00 55 30 00 55 01 21 F0 84 00 28 40 2F 9F BD 00 55 40 00 00 00 FF FF FF FF FF 9F 00 55 00 21 F0 54 01 1F 38 FF FF 47 00 55 70 00 00 00 FF FF FF FF FF 8F 00 55 01 21 E0 84 00 28 40 2F 9F BD 00 55 C0 00 55 00 21 E0 54 01 1F 38 FF FF 47 00 55 30 00 55 01 21 E0 84 00 28 40 2F BF BD 00 55 40 00 00 00 FF FF FF FF FF 9F 00 55 00 21 F0 54 01 1F 38 FF FF 47 00 55 E0 00 00 00 FF FF FF FF FF 8F 00 55 01 21 E0 84 00 28 40 2F 9F BD 00 55 C0 00 55 00 21 E0 54 01 1F 38 FF FF 47 00 55 20 00 55 01 21 F0 84 00 28 40 2F BF BD 00 55 40 00 00 00 FF FF FF FF FF 9F 00 55 00 21 E0 54 01 1F 38 FF FF 47 00 55 E0 00 00 00 FF FF FF FF FF 8F 00 55 01 21 F0 84 00 28 40 2F 9F BD 00 55 C0 00 55 00 21 E0 54 01 1F 38 FF FF 47 00 55 30 00 55 01 21 F0 84 00 28 40 2F BF BD 00 55 40 00 00 00 FF FF FF FF FF 9F 00 55 00 21 F0 54 01 3F 38 FF FF 47 00 55 E0 00 00 00 FF FF FF FF FF 8F 00 55 01 21 E0 84 00 28 40 2F 9F BD 00 55 C0 00 55 00 21 E0 54 01 1F 38 FF FF 47 00 55 30 00 55 01 21 F0 84 00 28 40 2F 9F BD 00 55 40 00 00 00 FF FF FF FF FF 9F 00 55 00 21 E0 54 01 3F 38 FF FF 47 00 55 E0 00 00 00 FF FF FF FF FF 8F 00 55 01 21 E0 84 00 28 40 2F 9F BD 00 55 C0 00 55 00 21 E0 54 01 1F 38 FF FF 47 00 55 20 00 55 01 21 E0 84 00 28 40 2F 9F BD 00 55 40 00 00 00 FF FF FF FF FF 9F 00 55 00 21 F0 54 01 1F 38 FF FF 47 00 55 E0 00 00 00 FF FF FF FF FF 8F 00 55 01 21 E0 84 00 28 40 2F BF BD 00 55 C0 00 55 00 21 F0 54 01 3F 38 FF FF 47 00 55 20 00 55 01 21 E0 84 00 28 40 2F 9F BD 00 55 40 00 00 00 FF FF FF FF FF 9F 00 55 00 21 E0 54 01 1F 38 FF FF 47 00 55 70 00 00 00 FF FF FF FF FF 8F 00 55 01 21 E0 84 00 28 40 2F 9F BD 00 55 C0 00 55 00 21 E0 54 01 1F 38 FF FF 47 00 55 20 00 55 01 21 F0 84 00 28 40 2F 9F BD 00 55 40 00 00 00 FF FF FF FF FF 9F 00 55 00 21 E0 54 01 1F 38 FF FF 47 00 55 E0 00 00 00 FF FF FF FF FF 8F 00 55 01 21 F0 84 00 28 40 2F 9F BD 00 55 C0 00 55 00 21 F0 54 01 1F 38 FF FF 47 00 55 30 00 55 01 21 F0 84 00 28 40 2F BF BD 00 55 40 00 00 00 FF FF FF FF FF 9F 00 55 00 21 F0 54 01 1F 38 FF FF 47 00 55 70 00 00 00 FF FF FF FF FF 8F 00 55 01 21 F0 84 00 28 40 2F BF BD 00 55 C0 00 55 00 21 E0 54 01 1F 38 FF FF 47 00 55 30 00 55 01 21 F0 84 00 28 40 2F 9F BD 00 55 40 00 00 00 FF FF FF FF FF 9F 00 55 00 21 E0 54 01 1F 38 FF FF 47 00 55 E0 00 00 00 FF FF FF FF FF 8F 00 55 01 21 F0 84 00 28 40 2F 9F BD 00 55 C0 00 55 00 21 E0 54 01 1F 38 FF FF 47 00 55 20 00 55 01 21 E0 84 00 28 40 2F 9F BD 00 55 40 00 00 00 FF FF FF FF FF 9F 00 55 00 21 E0 54 01 1F 38 FF FF 47 00 55 70 00 00 00 FF FF FF FF FF 8F 00 55 01 21 F0 84 00 28 40 2F 9F BD 00 55 C0 00 55 00 21 F0 54 01 3F 38 FF FF 47 00 55 20 00 55 01 21 E0 84 00 28 40 2F 9F BD 00 55 40 00 00 00 FF FF FF FF FF 9F 00 55 00 21 F0 54 01 3F 38 FF FF 47 00 55 E0 00 00 00 FF FF FF FF FF 8F 00 55 01 21 E0 84 00 28 40 2F 9F BD 00 55 C0 00 55 00 21 E0 54 01 1F 38 FF FF 47 00 55 20 00 55 01 21 F0 84 00 28 40 2F 9F BD 00 55 40 00 00 00 FF FF FF FF FF 9F 00 55 00 21 E0 54 01 1F 38 FF FF 47 00 55 70 00 00 00 FF FF FF FF FF 8F 00 55 01 21 F0 84 00 28 40 2F 9F BD 00 55 C0 00 55 00 21 E0 54 01 1F 38 FF FF 47 00 55 30 00 55 01 21 E0 84 00 28 40 2F 9F BD 00 55 40 00 00 00 FF FF FF FF FF 9F 00 55 00 21 E0 54 01 3F 38 FF FF 47 00 55 E0 00 00 00 FF FF FF FF FF 8F 00 55 01 21 F0 84 00 28 40 2F 9F BD 00 55 C0 00 55 00 21 E0 54 01 1F 38 FF FF 47 00 55 30 00 55 01 21 F0 84 00 28 40 2F BF BD 00 55 40 00 00 00 FF FF FF FF FF 9F 00 55 00 21 E0 54 01 1F 38 FF FF 47 00 55 E0 00 00 00 FF FF FF FF FF 8F 00 55 01 21 E0 84 00 28 40 2F BF BD 00 55 C0 00 55 00 21 E0 54 01 1F 38 FF FF 47 00 55 30 00 55 01 21 E0 84 00 28 40 2F 9F BD 00 55 40 00 00 00 FF FF FF FF FF 9F 00 55 00 21 F0 54 01 1F 38 FF FF 47 00 55 E0 00 00 00 FF FF FF FF FF 8F 00 55 01 21 F0 84 00 28 40 2F BF BD 00 55 C0 00 55 00 21 E0 54 01 1F 38 FF FF 47 00 55 20 00 55 01 21 E0 84 00 28 40 2F BF BD 00 55 40 00 00 00 FF FF FF FF FF 9F 00 55 00 21 E0 54 01 1F 38 FF FF 47 00 55 E0 00 00 00 FF FF FF FF FF 8F 00 55 01 21 F0 84 00 28 40 2F 9F BD 00 55 C0 00 55 00 21 F0 54 01 3F 38 FF FF 47 00 55 20 00 55 01 21 F0 84 00 28 40 2F BF BD 00 55 40 00 00 00 FF FF FF FF FF 9F 00 55 00 21 E0 54 01 1F 38 FF FF 47 00 55 70 00 00 00 FF FF FF FF FF 8F 00 55 01 21 E0 84 00 28 40 2F 9F BD 00 55 C0 00 55 00 21 E0 54 01 1F 38 FF FF 47 00 55 20 00 55 01 21 E0 84 00 28 40 2F 9F BD 00 55 40 00 00 00 FF FF FF FF FF 9F 00 55 00 21 E0 54 01 1F 38 FF FF 47 00 55 E0 00 00 00 FF FF FF FF FF 8F 00 55 01 21 E0 84 00 28 40 2F BF BD 00 55 C0 00 55 00 21 F0 54 01 3F 38 FF FF 47 00 55 30 00 55 01 21 E0 84 00 28 40 2F 9F BD 00 55 40 00 00 00 FF FF FF FF FF 9F 00 55 00 21 F0 54 01 1F 38 FF FF 47 00 55 70 00 00 00 FF FF FF FF FF 8F 00 55 01 21 F0 84 00 28 40 2F 9F BD 00 55 C0 00 55 00 21 F0 54 01 1F 38 FF FF 47 00 55 30 00 55 01 21 F0 84 00 28 40 2F BF BD 00 55 40 00 00 00 FF FF FF FF FF 9F 00 55 00 21 E0 54 01 3F 38 FF FF 47 00 55 E0 00 00 00 FF FF FF FF FF 8F 00 55 01 21 F0 84 00 28 40 2F 9F BD 00 55 C0 00 55 00 21 F0 54 01 1F 38 FF FF 47 00 55 30 00 55 01 21 F0 84 00 28 40 2F 9F BD 00 55 40 00 00 00 FF FF FF FF FF 9F 00 55 00 21 F0 54 01 1F 38 FF FF 47 00 55 70 00 00 00 FF FF FF FF FF 8F 00 55 01 21 E0 84 00 28 40 2F 9F BD 00 55 C0 00 55 00 21 F0 54 01 1F 38 FF FF 47 00 55 30 00 55 01 21 F0 84 00 28 40 2F 9F BD 00 55 40 00 00 00 FF FF FF FF FF 5F 00 55 00 21 F0 54 01 1F 38 FF FF 47 00 55 70 00 00 00 FF FF FF FF FF 8F 00 55 01 21 E0 84 00 28 40 2F 9F BD 00 55 C0 00 55 00 21 F0 54 01 1F 38 FF FF 47 00 55 30 00 55 01 21 F0 84 00 28 40 2F 9F BD 00 55 40 00 00 00 FF FF FF FF FF 9F 00 55 00 21 F0 54 01 3F 38 FF FF 47 00 55 E0 00 00 00 FF FF FF FF FF 8F 00 55 01 21 E0 84 00 28 40 2F 9F BD 00 55 C0 00 55 00 21 E0 54 01 1F 38 FF FF 47 00 55 20 00 55 01 21 F0 84 00 28 40 2F 9F BD 00 55 40 00 00 00 FF FF FF FF FF 9F 00 55 00 21 F0 54 01 1F 38 FF FF 47 00 55 70 00 00 00 FF FF FF FF FF 8F 00 55 01 21 E0 84 00 28 40 2F 9F BD 00 55 C0 00 55 00 21 E0 54 01 3F 38 FF FF 47 00 55 30 00 55 01 21 E0 84 00 28 40 2F 9F BD 00 55 40 00 00 00 FF FF FF FF FF 9F 00 55 00 21 F0 54 01 1F 38 FF FF 47 00 55 70 00 00 00 FF FF FF FF FF 8F 00 55 01 21 F0 84 00 28 40 2F 9F BD 00 55 C0 00 55 00 21 E0 54 01 3F 38 FF FF 47 00 55 20 00 55 01 21 F0 84 00 28 40 2F 9F BD 00 55 40 00 00 00 FF FF FF FF FF 9F 00 55 00 21 F0 54 01 1F 38 FF FF 47 00 55 E0 00 00 00 FF FF FF FF FF 8F 00 55 01 21 F0 84 00 28 40 2F 9F BD 00 55 C0 00 55 00 21 F0 54 01 1F 38 FF FF 47 00 55 30 00 55 01 21 E0 84 00 28 40 2F 9F BD 00 55 40 00 00 00 FF FF FF FF FF 9F 00 55 00 21 F0 54 01 1F 38 FF FF 47 00 55 70 00 00 00 FF FF FF FF FF 8F 00 55 01 21 E0 84 00 28 40 2F 9F BD 00 55 C0 00 55 00 21 F0 54 01 1F 38 FF FF 47 00 55 30 00 55 01 21 F0 84 00 28 40 2F 9F BD 00 55 40 00 00 00 FF FF FF FF FF 9F 00 55 00 21 F0 54 01 1F 38 FF FF 47 00 55 70 00 00 00 FF FF FF FF FF 8F 00 55 01 21 F0 84 00 28 40 2F 9F BD 00 55 C0 00 55 00 21 E0 54 01 1F 38 FF FF 47 00 55 30 00 55 01 21 E0 84 00 28 40 2F 9F BD 00 55 40 00 00 00 FF FF FF FF FF 9F 00 55 00 21 F0 54 01 1F 38 FF FF 47 00 55 E0 00 00 00 FF FF FF FF FF 8F 00 55 01 21 F0 84 00 28 40 2F BF BD 00 55 C0 00 55 00 21 F0 54 01 1F 38 FF FF 47 00 55 30 00 55 01 21 F0 84 00 28 40 2F 9F BD 00 55 40 00 00 00 FF FF FF FF FF 5F 00 55 00 21 F0 54 01 1F 38 FF FF 47 00 55 70 00 00 00 FF FF FF FF FF 8F 00 55 01 21 E0 84 00 28 40 2F 9F BD 00 55 C0 00 55 00 21 E0 54 01 3F 38 FF FF 47 00 55 30 00 55 01 21 E0 84 00 28 40 2F 9F BD 00 55 40 00 00 00 FF FF FF FF FF 9F 00 55 00 21 F0 54 01 1F 38 FF FF 47 00 55 70 00 00 00 FF FF FF FF FF 8F 00 55 01 21 F0 84 00 28 40 2F BF BD 00 55 C0 00 55 00 21 F0 54 01 1F 38 FF FF 47 00 55 20 00 55 01 21 E0 84 00 28 40 2F 9F BD 00 55 40 00 00 00 FF FF FF FF FF 9F 00 55 00 21 E0 54 01 1F 38 FF FF 47 00 55 E0 00 00 00 FF FF FF FF FF 8F 00 55 01 21 F0 84 00 28 40 2F 9F BD 00 55 C0 00 55 00 21 F0 54 01 1F 38 FF FF 47 00 55 30 00 55 01 21 E0 84 00 28 40 2F 9F BD 00 55 40 00 00 00 FF FF FF FF FF 9F 00 55 00 21 F0 54 01 1F 38 FF FF 47 00 55 E0 00 00 00 FF FF FF FF FF 8F 00 55 01 21 F0 84 00 28 40 2F 9F BD 00 55 C0 00 55 00 21 F0 54 01 1F 38 FF FF 47 00 55 30 00 55 01 21 F0 84 00 28 40 2F 9F BD 00 55 40 00 00 00 FF FF FF FF FF 9F 00 55 00 21 E0 54 01 1F 38 FF FF 47 00 55 70 00 00 00 FF FF FF FF FF 8F 00 55 01 21 F0 84 00 28 40 2F BF BD 00 55 C0 00 55 00 21 E0 54 01 1F 38 FF FF 47 00 55 30 00 55 01 21 F0 84 00 28 40 2F 9F BD 00 55 40 00 00 00 FF FF FF FF FF 5F 00 55 00 21 F0 54 01 1F 38 FF FF 47 00 55 70 00 00 00 FF FF FF FF FF 8F 00 55 01 21 E0 84 00 28 40 2F 9F BD 00 55 C0 00 55 00 21 E0 54 01 1F 38 FF FF 47 00 55 20 00 55 01 21 E0 84 00 28 40 2F 9F BD 00 55 40 00 00 00 FF FF FF FF FF 5F 00 55 00 21 F0 54 01 1F 38 FF FF 47 00 55 70 00 00 00 FF FF FF FF FF 8F 00 55 01 21 F0 84 00 28 40 2F BF BD 00 55 C0 00 55 00 21 E0 54 01 1F 38 FF FF 47 00 55 30 00 55 01 21 F0 84 00 28 40 2F 9F BD 00 55 40 00 00 00 FF FF FF FF FF 5F 00 55 00 21 F0 54 01 1F 38 FF FF 47 00 55 E0 00 00 00 FF FF FF FF FF 8F 00 55 01 21 F0 84 00 28 40 2F 9F BD 00 55 C0 00 55 00 21 E0 54 01 1F 38 FF FF 47 00 55 20 00 55 01 21 F0 84 00 28 40 2F 9F BD 00 55 40 00 00 00 FF FF FF FF FF 9F 00 55 00 21 F0 54 01 1F 38 FF FF 47 00 55 70 00 00 00 FF FF FF FF FF 8F 00 55 01 21 F0 84 00 28 40 2F 9F BD 00 55 C0 00 55 00 21 E0 54 01 1F 38 FF FF 47 00 55 30 00 55 01 21 F0 84 00 28 40 2F BF BD 00 55 40 00 00 00 FF FF FF FF FF 9F 00 55 00 21 F0 54 01 1F 38 FF FF 47 00 55 E0 00 00 00 FF FF FF FF FF 8F 00 55 01 21 F0 84 00 28 40 2F 9F BD 00 55 C0 00 55 00 21 E0 54 01 1F 38 FF FF 47 00 55 20 00 55 01 21 E0 84 00 28 40 2F 9F BD 00 55 40 00 00 00 FF FF FF FF FF 9F 00 55 00 21 F0 54 01 3F 38 FF FF 47 00 55 E0 00 00 00 FF FF FF FF FF 8F 00 55 01 21 F0 84 00 28 40 2F 9F BD 00 55 C0 00 55 00 21 F0 54 01 1F 38 FF FF 47 00 55 30 00 55 01 21 F0 84 00 28 40 2F 9F BD 00 55 40 00 00 00 FF FF FF FF FF 9F 00 55 00 21 E0 54 01 1F 38 FF FF 47 00 55 70 00 00 00 FF FF FF FF FF 8F 00 55 01 21 F0 84 00 28 40 2F 9F BD 00 55 C0 00 55 00 21 F0 54 01 1F 38 FF FF 47 00 55 30 00 55 01 21 F0 84 00 28 40 2F BF BD 00 55 40 00 00 00 FF FF FF FF FF 5F 00 55 00 21 E0 54 01 3F 38 FF FF 47 00 55 70 00 00 00 FF FF FF FF FF 8F 00 55 01 21 E0 84 00 28 40 2F 9F BD 00 55 C0 00 55 00 21 F0 54 01 1F 38 FF FF 47 00 55 30 00 55 01 21 F0 84 00 28 40 2F 9F BD 00 55 40 00 00 00 FF FF FF FF FF 9F 00 55 00 21 E0 54 01 3F 38 FF FF 47 00 55 70 00 00 00 FF FF FF FF FF 8F 00 55 01 21 F0 84 00 28 40 2F 9F BD 00 55 C0 00 55 00 21 F0 54 01 1F 38 FF FF 47 00 55 30 00 55 01 21 F0 84 00 28 40 2F 9F BD 00 55 40 00 00 00 FF FF FF FF FF 9F 00 55 00 21 F0 54 01 1F 38 FF FF 47 00 55 70 00 00 00 FF FF FF FF FF 8F 00 55 01 21 F0 84 00 28 40 2F 9F BD 00 55 C0 00 55 00 21 E0 54 01 1F 38 FF FF 47 00 55 30 00 55 01 21 E0 84 00 28 40 2F 9F BD 00 55 40 00 00 00 FF FF FF FF FF 5F 00 55 00 21 E0 54 01 1F 38 FF FF 47 00 55 E0 00 00 00 FF FF FF FF FF 8F 00 55 01 21 E0 84 00 28 40 2F 9F BD 00 55 C0 00 55 00 21 E0 54 01 1F 38 FF FF 47 00 55 30 00 55 01 21 F0 84 00 28 40 2F 9F BD 00 55 40 00 00 00 FF FF FF FF FF 5F 00 55 00 21 F0 54 01 1F 38 FF FF 47 00 55 70 00 00 00 FF FF FF FF FF 8F 00 55 01 21 E0 84 00 28 40 2F 9F BD 00 55 C0 00 55 00 21 F0 54 01 1F 38 FF FF 47 00 55 20 00 55 01 21 E0 84 00 28 40 2F 9F BD 00 55 40 00 00 00 FF FF FF FF FF 9F 00 55 00 21 F0 54 01 1F 38 FF FF 47 00 55 70 00 00 00 FF FF FF FF FF 8F 00 55 01 21 F0 84 00 28 40 2F 9F BD 00 55 C0 00 55 00 21 F0 54 01 1F 38 FF FF 47 00 55 30 00 55 01 21 F0 84 00 28 40 2F 9F BD 00 55 40 00 00 00 FF FF FF FF FF 9F 00 55 00 21 F0 54 01 1F 38 FF FF 47 00 55 70 00 00 00 FF FF FF FF FF 8F 00 55 01 21 E0 84 00 28 40 2F BF BD 00 55 C0 00 55 00 21 F0 54 01 1F 38 FF FF 47 00 55 30 00 55 01 21 E0 84 00 28 40 2F 9F BD 00 55 40 00 00 00 FF FF FF FF FF 9F 00 55 00 21 E0 54 01 3F 38 FF FF 47 00 55 70 00 00 00 FF FF FF FF FF 8F 00 55 01 21 E0 84 00 28 40 2F 9F BD 00 55 C0 00 55 00 21 F0 54 01 1F 38 FF FF 47 00 55 20 00 55 01 21 F0 84 00 28 40 2F 9F BD 00 55 40 00 00 00 FF FF FF FF FF 5F 00 55 00 21 F0 54 01 1F 38 FF FF 47 00 55 E0 00 00 00 FF FF FF FF FF 8F 00 55 01 21 E0 84 00 28 40 2F 9F BD 00 55 C0 00 55 00 21 F0 54 01 1F 38 FF FF 47 00 55 30 00 55 01 21 E0 84 00 28 40 2F 9F BD 00 55 40 00 00 00 FF FF FF FF FF 9F 00 55 00 21 F0 54 01 1F 38 FF FF 47 00 55 E0 00 00 00 FF FF FF FF FF 8F 00 55 01 21 F0 84 00 28 40 2F 9F BD 00 55 C0 00 55 00 21 F0 54 01 1F 38 FF FF 47 00 55 30 00 55 01 21 F0 84 00 28 40 2F 9F BD 00 55 40 00 00 00 FF FF FF FF FF 9F 00 55 00 21 E0 54 01 1F 38 FF FF 47 00 55 70 00 00 00 FF FF FF FF FF 8F 00 55 01 21 F0 84 00 28 40 2F 9F BD 00 55 C0 00 55 00 21 F0 54 01 1F 38 FF FF 47 00 55 30 00 55 01 21 F0 84 00 28 40 2F 9F BD 00 55 40 00 00 00 FF FF FF FF FF 9F 00 55 00 21 F0 54 01 1F 38 FF FF 47 00 55 70 00 00 00 FF FF FF FF FF 8F 00 55 01 21 F0 84 00 28 40 2F 9F BD 00 55 C0 00 55 00 21 F0 54 01 1F 38 FF FF 47 00 55 20 00 55 01 21 F0 84 00 28 40 2F BF BD 00 55 40 00 00 00 FF FF FF FF FF 9F 00 55 00 21 E0 54 01 3F 38 FF FF 47 00 55 70 00 00 00 FF FF FF FF FF 8F 00 55 01 21 F0 84 00 28 40 2F 9F BD 00 55 C0 00 55 00 21 F0 54 01 1F 38 FF FF 47 00 55 20 00 55 01 21 E0 84 00 28 40 2F 9F BD 00 55 40 00 00 00 FF FF FF FF FF 9F 00 55 00 21 F0 54 01 1F 38 FF FF 47 00 55 70 00 00 00 FF FF FF FF FF 8F 00 55 01 21 F0 84 00 28 40 2F BF BD 00 55 C0 00 55 00 21 F0 54 01 1F 38 FF FF 47 00 55 30 00 55 01 21 F0 84 00 28 40 2F 9F BD 00 55 40 00 00 00 FF FF FF FF FF 9F 00 55 00 21 F0 54 01 1F 38 FF FF 47 00 55 70 00 00 00 FF FF FF FF FF 8F 00 55 01 21 E0 84 00 28 40 2F 9F BD 00 55 C0 00 55 00 21 F0 54 01 1F 38 FF FF 47 00 55 20 00 55 01 21 F0 84 00 28 40 2F 9F BD 00 55 40 00 00 00 FF FF FF FF FF 9F 00 55 00 21 F0 54 01 1F 38 FF FF 47 00 55 E0 00 00 00 FF FF FF FF FF 8F 00 55 01 21 F0 84 00 28 40 2F 9F BD 00 55 C0 00 55 00 21 E0 54 01 3F 38 FF FF 47 00 55 30 00 55 01 21 E0 84 00 28 40 2F 9F BD 00 55 40 00 00 00 FF FF FF FF FF 9F 00 55 00 21 F0 54 01 1F 38 FF FF 47 00 55 E0 00 00 00 FF FF FF FF FF 8F 00 55 01 21 F0 84 00 28 40 2F 9F BD 00 55 C0 00 55 00 21 F0 54 01 1F 38 FF FF 47 00 55 20 00 55 01 21 F0 84 00 28 40 2F 9F BD 00 55 40 00 00 00 FF FF FF FF FF 5F 00 55 00 21 F0 54 01 1F 38 FF FF 47 00 55 70 00 00 00 FF FF FF FF FF 8F 00 55 01 21 E0 84 00 28 40 2F 9F BD 00 55 C0 00 55 00 21 E0 54 01 3F 38 FF FF 47 00 55 30 00 55 01 21 F0 84 00 28 40 2F 9F BD 00 55 40 00 00 00 FF FF FF FF FF 9F 00 55 00 21 F0 54 01 1F 38 FF FF 47 00 55 70 00 00 00 FF FF FF FF FF 8F 00 55 01 21 F0 84 00 28 40 2F BF BD 00 55 C0 00 55 00 21 F0 54 01 1F 38 FF FF 47 00 55 30 00 55 01 21 F0 84 00 28 40 2F BF BD 00 55 40 00 00 00 FF FF FF FF FF 9F 00 55 00 21 F0 54 01 1F 38 FF FF 47 00 55 70 00 00 00 FF FF FF FF FF 8F 00 55 01 21 F0 84 00 28 40 2F 9F BD 00 55 C0 00 55 00 21 E0 54 01 1F 38 FF FF 47 00 55 20 00 55 01 21 F0 84 00 28 40 2F 9F BD 00 55 40 00 00 00 FF FF FF FF FF 9F 00 55 00 21 E0 54 01 3F 38 FF FF 47 00 55 70 00 00 00 FF FF FF FF FF 8F 00 55 01 21 F0 84 00 28 40 2F 9F BD 00 55 C0 00 55 00 21 E0 54 01 1F 38 FF FF 47 00 55 30 00 55 01 21 F0 84 00 28 40 2F 9F BD 00 55 40 00 00 00 FF FF FF FF FF 9F 00 55 00 21 F0 54 01 1F 38 FF FF 47 00 55 70 00 00 00 FF FF FF FF FF 8F 00 55 01 21 F0 84 00 28 40 2F 9F BD 00 55 C0 00 55 00 21 F0 54 01 1F 38 FF FF 47 00 55 20 00 55 01 21 F0 84 00 28 40 2F 9F BD 00 55 40 00 00 00 FF FF FF FF FF 9F 00 55 00 21 E0 54 01 1F 38 FF FF 47 00 55 70 00 00 00 FF FF FF FF FF 8F 00 55 01 21 E0 84 00 28 40 2F 9F BD 00 55 C0 00 55 00 21 F0 54 01 1F 38 FF FF 47 00 55 30 00 55 01 21 F0 84 00 28 40 2F 9F BD 00 55 40 00 00 00 FF FF FF FF FF 9F 00 55 00 21 F0 54 01 1F 38 FF FF 47 00 55 70 00 00 00 FF FF FF FF FF 8F 00 55 01 21 E0 84 00 28 40 2F BF BD 00 55 C0 00 55 00 21 F0 54 01 1F 38 FF FF 47 00 55 20 00 55 01 21 F0 84 00 28 40 2F 9F BD 00 55 40 00 00 00 FF FF FF FF FF 9F 00 55 00 21 F0 54 01 1F 38 FF FF 47 00 55 E0 00 00 00 FF FF FF FF FF 8F 00 55 01 21 F0 84 00 28 40 2F 9F BD 00 55 C0 00 55 00 21 E0 54 01 3F 38 FF FF 47 00 55 20 00 55 01 21 F0 84 00 28 40 2F 9F BD 00 55 40 00 00 00 FF FF FF FF FF 9F 00 55 00 21 F0 54 01 1F 38 FF FF 47 00 55 E0 00 00 00 FF FF FF FF FF 8F 00 55 01 21 F0 84 00 28 40 2F BF BD 00 55 C0 00 55 00 21 F0 54 01 1F 38 FF FF 47 00 55 20 00 55 01 21 F0 84 00 28 40 2F BF BD 00 55 40 00 00 00 FF FF FF FF FF 5F 00 55 00 21 F0 54 01 1F 38 FF FF 47 00 55 70 00 00 00 FF FF FF FF FF 8F 00 55 01 21 E0 84 00 28 40 2F 9F BD 00 55 C0 00 55 00 21 E0 54 01 1F 38 FF FF 47 00 55 30 00 55 01 21 E0 84 00 28 40 2F 9F BD 00 55 40 00 00 00 FF FF FF FF FF 9F 00 55 00 21 E0 54 01 3F 38 FF FF 47 00 55 70 00 00 00 FF FF FF FF FF 8F 00 55 01 21 E0 84 00 28 40 2F 9F BD 00 55 C0 00 55 00 21 F0 54 01 1F 38 FF FF 47 00 55 30 00 55 01 21 F0 84 00 28 40 2F 9F BD 00 55 40 00 00 00 FF FF FF FF FF 9F 00 55 00 21 E0 54 01 3F 38 FF FF 47 00 55 70 00 00 00 FF FF FF FF FF 8F 00 55 01 21 E0 84 00 28 40 2F 9F BD 00 55 C0 00 55 00 21 F0 54 01 1F 38 FF FF 47 00 55 30 00 55 01 21 E0 84 00 28 40 2F BF BD 00 55 40 00 00 00 FF FF FF FF FF 5F 00 55 00 21 F0 54 01 1F 38 FF FF 47 00 55 E0 00 00 00 FF FF FF FF FF 8F 00 55 01 21 E0 84 00 28 40 2F 9F BD 00 55 C0 00 55 00 21 F0 54 01 1F 38 FF FF 47 00 55 20 00 55 01 21 F0 84 00 28 40 2F 9F BD 00 55 40 00 00 00 FF FF FF FF FF 9F 00 55 00 21 F0 54 01 1F 38 FF FF 47 00 55 E0 00 00 00 FF FF FF FF FF 8F 00 55 01 21 E0 84 00 28 40 2F BF BD 00 55 C0 00 55 00 21 E0 54 01 1F 38 FF FF 47 00 55 30 00 55 01 21 F0 84 00 28 40 2F 9F BD 00 55 40 00 00 00 FF FF FF FF FF 9F 00 55 00 21 F0 54 01 1F 38 FF FF 47 00 55 E0 00 00 00 FF FF FF FF FF 8F 00 55 01 21 F0 84 00 28 40 2F 9F BD 00 55 C0 00 55 00 21 F0 54 01 1F 38 FF FF 47 00 55 30 00 55 01 21 E0 84 00 28 40 2F 9F BD 00 55 40 00 00 00 FF FF FF FF FF 9F 00 55 00 21 E0 54 01 1F 38 FF FF 47 00 55 70 00 00 00 FF FF FF FF FF 8F 00 55 01 21 F0 84 00 28 40 2F BF BD 00 55 C0 00 55 00 21 F0 54 01 1F 38 FF FF 47 00 55 30 00 55 01 21 F0 84 00 28 40 2F 9F BD 00 55 40 00 00 00 FF FF FF FF FF 9F 00 55 00 21 F0 54 01 1F 38 FF FF 47 00 55 70 00 00 00 FF FF FF FF FF 8F 00 55 01 21 F0 84 00 28 40 2F 9F BD 00 55 C0 00 55 00 21 F0 54 01 1F 38 FF FF 47 00 55 30 00 55 01 21 F0 84 00 28 40 2F 9F BD 00 55 40 00 00 00 FF FF FF FF FF 9F 00 55 00 21 F0 54 01 1F 38 FF FF 47 00 55 70 00 00 00 FF FF FF FF FF 8F 00 55 01 21 E0 84 00 28 40 2F BF BD 00 55 C0 00 55 00 21 F0 54 01 1F 38 FF FF 47 00 55 30 00 55 01 21 F0 84 00 28 40 2F 9F BD 00 55 40 00 00 00 FF FF FF FF FF 9F 00 55 00 21 F0 54 01 1F 38 FF FF 47 00 55 70 00 00 00 FF FF FF FF FF 8F 00 55 01 21 F0 84 00 28 40 2F BF BD 00 55 C0 00 55 00 21 F0 54 01 1F 38 FF FF 47 00 55 30 00 55 01 21 E0 84 00 28 40 2F 9F BD 00 55 40 00 00 00 FF FF FF FF FF 9F 00 55 00 21 E0 54 01 3F 38 FF FF 47 00 55 70 00 00 00 FF FF FF FF FF 8F 00 55 01 21 E0 84 00 28 40 2F BF BD 00 55 C0 00 55 00 21 F0 54 01 1F 38 FF FF 47 00 55 30 00 55 01 21 F0 84 00 28 40 2F 9F BD 00 55 40 00 00 00 FF FF FF FF FF 9F 00 55 00 21 F0 54 01 1F 38 FF FF 47 00 55 E0 00 00 00 FF FF FF FF FF 8F 00 55 01 21 E0 84 00 28 40 2F BF BD 00 55 C0 00 55 00 21 F0 54 01 1F 38 FF FF 47 00 55 20 00 55 01 21 E0 84 00 28 40 2F 9F BD 00 55 40 00 00 00 FF FF FF FF FF 9F 00 55 00 21 E0 54 01 3F 38 FF FF 47 00 55 E0 00 00 00 FF FF FF FF FF 8F 00 55 01 21 F0 84 00 28 40 2F 9F BD 00 55 C0 00 55 00 21 F0 54 01 1F 38 FF FF 47 00 55 30 00 55 01 21 E0 84 00 28 40 2F BF BD 00 55 40 00 00 00 FF FF FF FF FF 5F 00 55 00 21 F0 54 01 1F 38 FF FF 47 00 55 70 00 00 00 FF FF FF FF FF 8F 00 55 01 21 F0 84 00 28 40 2F 9F BD 00 55 C0 00 55 00 21 F0 54 01 1F 38 FF FF 47 00 55 30 00 55 01 21 F0 84 00 28 40 2F 9F BD 00 55 40 00 00 00 FF FF FF FF FF 9F 00 55 00 21 F0 54 01 1F 38 FF FF 47 00 55 70 00 00 00 FF FF FF FF FF 8F 00 55 01 21 F0 84 00 28 40 2F 9F BD 00 55 C0 00 55 00 21 E0 54 01 1F 38 FF FF 47 00 55 30 00 55 01 21 F0 84 00 28 40 2F 9F BD 00 55 40 00 00 00 FF FF FF FF FF 5F 00 55 00 21 F0 54 01 1F 38 FF FF 47 00 55 70 00 00 00 FF FF FF FF FF 8F 00 55 01 21 E0 84 00 28 40 2F 9F BD 00 55 C0 00 55 00 21 F0 54 01 1F 38 FF FF 47 00 55 30 00 55 01 21 F0 84 00 28 40 2F 9F BD 00 55 40 00 00 00 FF FF FF FF FF 9F 00 55 00 21 F0 54 01 1F 38 FF FF 47 00 55 E0 00 00 00 FF FF FF FF FF 8F 00 55 01 21 F0 84 00 28 40 2F 9F BD 00 55 C0 00 55 00 21 F0 54 01 1F 38 FF FF 47 00 55 20 00 55 01 21 E0 84 00 28 40 2F 9F BD 00 55 40 00 00 00 FF FF FF FF FF 9F 00 55 00 21 F0 54 01 1F 38 FF FF 47 00 55 E0 00 00 00 FF FF FF FF FF 8F 00 55 01 21 F0 84 00 28 40 2F 9F BD 00 55 C0 00 55 00 21 F0 54 01 1F 38 FF FF 47 00 55 20 00 55 01 21 E0 84 00 28 40 2F BF BD 00 55 40 00 00 00 FF FF FF FF FF 9F 00 55 00 21 F0 54 01 1F 38 FF FF 47 00 55 E0 00 00 00 FF FF FF FF FF 8F 00 55 01 21 F0 84 00 28 40 2F 9F BD 00 55 C0 00 55 00 21 F0 54 01 1F 38 FF FF 47 00 55 20 00 55 01 21 F0 84 00 28 40 2F BF BD 00 55 40 00 00 00 FF FF FF FF FF 9F 00 55 00 21 F0 54 01 1F 38 FF FF 47 00 55 70 00 00 00 FF FF FF FF FF 8F 00 55 01 21 F0 84 00 28 40 2F 9F BD 00 55 C0 00 55 00 21 F0 54 01 1F 38 FF FF 47 00 55 20 00 55 01 21 F0 84 00 28 40 2F 9F BD 00 55 40 00 00 00 FF FF FF FF FF 5F 00 55 00 21 E0 54 01 1F 38 FF FF 47 00 55 70 00 00 00 FF FF FF FF FF 8F 00 55 01 21 E0 84 00 28 40 2F BF BD 00 55 C0 00 55 00 21 F0 54 01 1F 38 FF FF 47 00 55 20 00 55 01 21 E0 84 00 28 40 2F BF BD 00 55 40 00 00 00 FF FF FF FF FF 9F 00 55 00 21 E0 54 01 1F 38 FF FF 47 00 55 70 00 00 00 FF FF FF FF FF 8F 00 55 01 21 E0 84 00 28 40 2F BF BD 00 55 C0 00 55 00 21 E0 54 01 3F 38 FF FF 47 00 55 20 00 55 01 21 F0 84 00 28 40 2F 9F BD 00 55 40 00 00 00 FF FF FF FF FF 5F 00 55 00 21 F0 54 01 1F 38 FF FF 47 00 55 E0 00 00 00 FF FF FF FF FF 8F 00 55 01 21 F0 84 00 28 40 2F 9F BD 00 55 C0 00 55 00 21 F0 54 01 1F 38 FF FF 47 00 55 20 00 55 01 21 F0 84 00 28 40 2F 9F BD 00 55 40 00 00 00 FF FF FF FF FF 5F 00 55 00 21 E0 54 01 1F 38 FF FF 47 00 55 70 00 00 00 FF FF FF FF FF 8F 00 55 01 21 F0 84 00 28 40 2F 9F BD 00 55 C0 00 55 00 21 E0 54 01 1F 38 FF FF 47 00 55 20 00 55 01 21 F0 84 00 28 40 2F 9F BD 00 55 40 00 00 00 FF FF FF FF FF 5F 00 55 00 21 F0 54 01 1F 38 FF FF 47 00 55 70 00 00 00 FF FF FF FF FF 8F 00 55 01 21 F0 84 00 28 40 2F 9F BD 00 55 C0 00 55 00 21 F0 54 01 1F 38 FF FF 47 00 55 20 00 55 01 21 F0 84 00 28 40 2F 9F BD 00 55 40 00 00 00 FF FF FF FF FF 9F 00 55 00 21 E0 54 01 3F 38 FF FF 47 00 55 E0 00 00 00 FF FF FF FF FF 8F 00 55 01 21 E0 84 00 28 40 2F BF BD 00 55 C0 00 55 00 21 F0 54 01 1F 38 FF FF 47 00 55 20 00 55 01 21 F0 84 00 28 40 2F 9F BD 00 55 40 00 00 00 FF FF FF FF FF 9F 00 55 00 21 E0 54 01 3F 38 FF FF 47 00 55 70 00 00 00 FF FF FF FF FF 8F 00 55 01 21 E0 84 00 28 40 2F BF BD 00 55 C0 00 55 00 21 E0 54 01 1F 38 FF FF 47 00 55 30 00 55 01 21 E0 84 00 28 40 2F 9F BD 00 55 40 00 00 00 FF FF FF FF FF 5F 00 55 00 21 F0 54 01 1F 38 FF FF 47 00 55 E0 00 00 00 FF FF FF FF FF 8F 00 55 01 21 E0 84 00 28 40 2F 9F BD 00 55 C0 00 55 00 21 F0 54 01 1F 38 FF FF 47 00 55 30 00 55 01 21 F0 84 00 28 40 2F 9F BD 00 55 40 00 00 00 FF FF FF FF FF 9F 00 55 00 21 E0 54 01 1F 38 FF FF 47 00 55 E0 00 00 00 FF FF FF FF FF 8F 00 55 01 21 F0 84 00 28 40 2F 9F BD 00 55 C0 00 55 00 21 E0 54 01 1F 38 FF FF 47 00 55 30 00 55 01 21 E0 84 00 28 40 2F BF BD 00 55 40 00 00 00 FF FF FF FF FF 9F 00 55 00 21 F0 54 01 1F 38 FF FF 47 00 55 70 00 00 00 FF FF FF FF FF 8F 00 55 01 21 F0 84 00 28 40 2F 9F BD 00 55 C0 00 55 00 21 E0 54 01 1F 38 FF FF 47 00 55 30 00 55 01 21 E0 84 00 28 40 2F 9F BD 00 55 40 00 00 00 FF FF FF FF FF 9F 00 55 00 21 F0 54 01 1F 38 FF FF 47 00 55 70 00 00 00 FF FF FF FF FF 8F 00 55 01 21 E0 84 00 28 40 2F BF BD 00 55 C0 00 55 00 21 F0 54 01 1F 38 FF FF 47 00 55 20 00 55 01 21 F0 84 00 28 40 2F 9F BD 00 55 40 00 00 00 FF FF FF FF FF 9F 00 55 00 21 F0 54 01 1F 38 FF FF 47 00 55 E0 00 00 00 FF FF FF FF FF 8F 00 55 01 21 E0 84 00 28 40 2F BF BD 00 55 C0 00 55 00 21 E0 54 01 3F 38 FF FF 47 00 55 30 00 55 01 21 F0 84 00 28 40 2F 9F BD 00 55 40 00 00 00 FF FF FF FF FF 9F 00 55 00 21 F0 54 01 1F 38 FF FF 47 00 55 70 00 00 00 FF FF FF FF FF 8F 00 55 01 21 F0 84 00 28 40 2F 9F BD 00 55 C0 00 55 00 21 E0 54 01 1F 38 FF FF 47 00 55 30 00 55 01 21 F0 84 00 28 40 2F 9F BD 00 55 40 00 00 00 FF FF FF FF FF 9F 00 55 00 21 F0 54 01 1F 38 FF FF 47 00 55 E0 00 00 00 FF FF FF FF FF 8F 00 55 01 21 F0 84 00 28 40 2F 9F BD 00 55 C0 00 55 00 21 F0 54 01 1F 38 FF FF 47 00 55 30 00 55 01 21 E0 84 00 28 40 2F 9F BD 00 55 40 00 00 00 FF FF FF FF FF 9F 00 55 00 21 E0 54 01 1F 38 FF FF 47 00 55 70 00 00 00 FF FF FF FF FF 8F 00 55 01 21 F0 84 00 28 40 2F 9F BD 00 55 C0 00 55 00 21 F0 54 01 1F 38 FF FF 47 00 55 30 00 55 01 21 E0 84 00 28 40 2F 9F BD 00 55 40 00 00 00 FF FF FF FF FF 9F 00 55 00 21 F0 54 01 1F 38 FF FF 47 00 55 E0 00 00 00 FF FF FF FF FF 8F 00 55 01 21 E0 84 00 28 40 2F 9F BD 00 55 C0 00 55 00 21 E0 54 01 1F 38 FF FF 47 00 55 30 00 55 01 21 F0 84 00 28 40 2F 9F BD 00 55 40 00 00 00 FF FF FF FF FF 9F 00 55 00 21 F0 54 01 1F 38 FF FF 47 00 55 E0 00 00 00 FF FF FF FF FF 8F 00 55 01 21 F0 84 00 28 40 2F 9F BD 00 55 C0 00 55 00 21 F0 54 01 1F 38 FF FF 47 00 55 30 00 55 01 21 F0 84 00 28 40 2F 9F BD 00 55 40 00 00 00 FF FF FF FF FF 9F 00 55 00 21 F0 54 01 1F 38 FF FF 47 00 55 70 00 00 00 FF FF FF FF FF 8F 00 55 01 21 F0 84 00 28 40 2F 9F BD 00 55 C0 00 55 00 21 F0 54 01 1F 38 FF FF 47 00 55 30 00 55 01 21 F0 84 00 28 40 2F 9F BD 00 55 40 00 00 00 FF FF FF FF FF 9F 00 55 00 21 E0 54 01 1F 38 FF FF 47 00 55 70 00 00 00 FF FF FF FF FF 8F 00 55 01 21 F0 84 00 28 40 2F 9F BD 00 55 C0 00 55 00 21 E0 54 01 3F 38 FF FF 47 00 55 20 00 55 01 21 E0 84 00 28 40 2F 9F BD 00 55 40 00 00 00 FF FF FF FF FF 9F 00 55 00 21 F0 54 01 1F 38 FF FF 47 00 55 E0 00 00 00 FF FF FF FF FF 8F 00 55 01 21 E0 84 00 28 40 2F 9F BD 00 55 C0 00 55 00 21 F0 54 01 1F 38 FF FF 47 00 55 30 00 55 01 21 F0 84 00 28 40 2F 9F BD 00 55 40 00 00 00 FF FF FF FF FF 9F 00 55 00 21 E0 54 01 3F 38 FF FF 47 00 55 70 00 00 00 FF FF FF FF FF 8F 00 55 01 21 E0 84 00 28 40 2F BF BD 00 55 C0 00 55 00 21 F0 54 01 1F 38 FF FF 47 00 55 20 00 55 01 21 F0 84 00 28 40 2F 9F BD 00 55 40 00 00 00 FF FF FF FF FF 9F 00 55 00 21 F0 54 01 1F 38 FF FF 47 00 55 E0 00 00 00 FF FF FF FF FF 8F 00 55 01 21 F0 84 00 28 40 2F 9F BD 00 55 C0 00 55 00 21 F0 54 01 1F 38 FF FF 47 00 55 30 00 55 01 21 F0 84 00 28 40 2F BF BD 00 55 40 00 00 00 FF FF FF FF FF 9F 00 55 00 21 E0 54 01 1F 38 FF FF 47 00 55 70 00 00 00 FF FF FF FF FF 8F 00 55 01 21 F0 84 00 28 40 2F 9F BD 00 55 C0 00 55 00 21 F0 54 01 1F 38 FF FF 47 00 55 20 00 55 01 21 F0 84 00 28 40 2F 9F BD 00 55 40 00 00 00 FF FF FF FF FF 9F 00 55 00 21 E0 54 01 1F 38 FF FF 47 00 55 E0 00 00 00 FF FF FF FF FF 8F 00 55 01 21 E0 84 00 28 40 2F 9F BD 00 55 C0 00 55 00 21 F0 54 01 1F 38 FF FF 47 00 55 20 00 55 01 21 F0 84 00 28 40 2F 9F BD 00 55 40 00 00 00 FF FF FF FF

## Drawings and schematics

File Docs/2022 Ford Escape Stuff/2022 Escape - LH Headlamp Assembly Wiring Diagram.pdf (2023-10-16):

10/16/23, 11:54 AM | about:blank

## LED

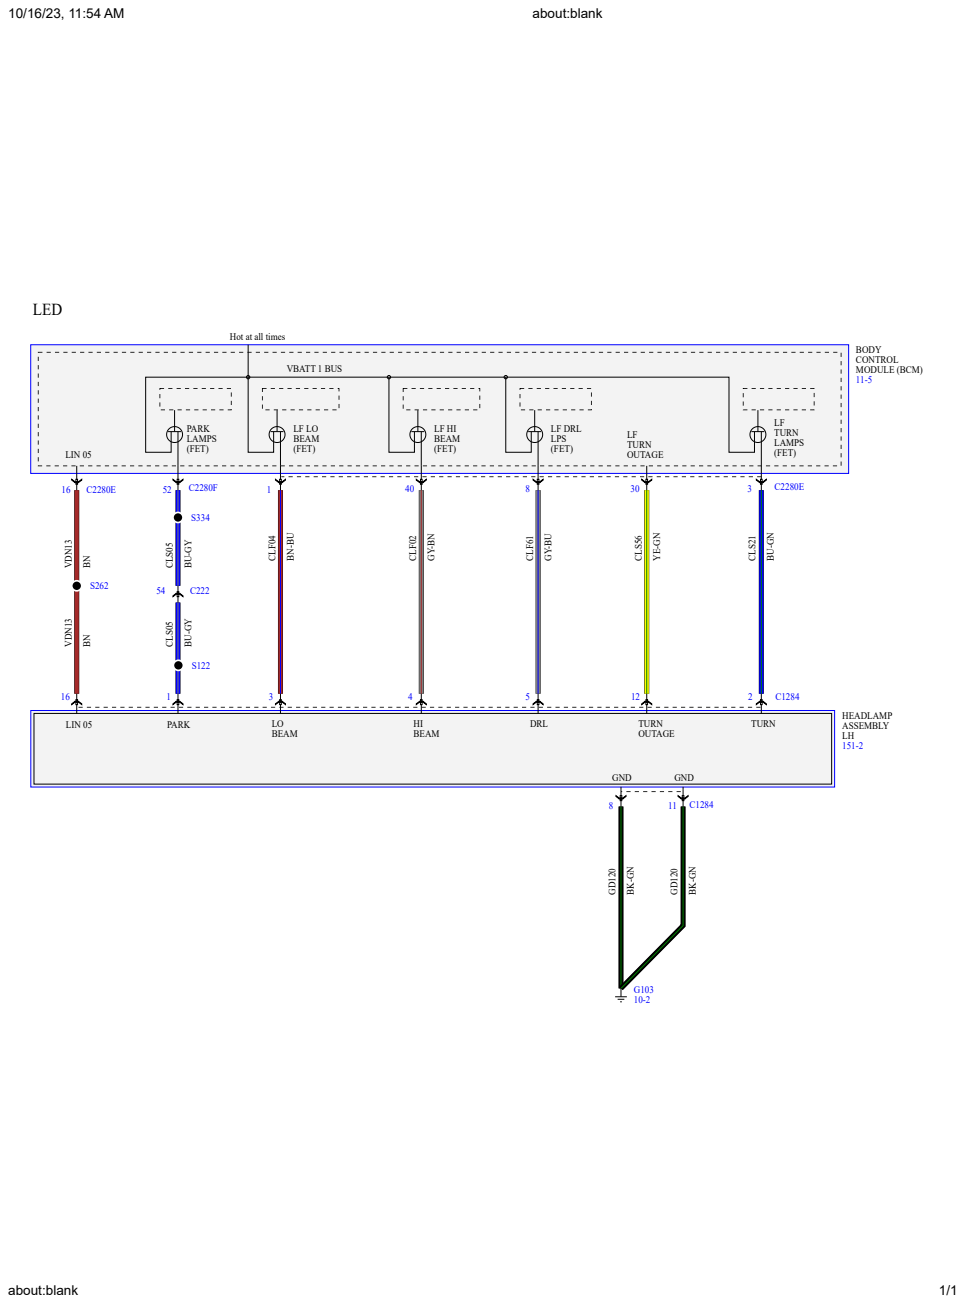
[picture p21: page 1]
about:blank; CLF04; VDN13; CLS56; CLF02; CLF61; CLS21; CLS05; MODULE (BCM); CONTROL; BODY; LF LO BEAM (FET); LF DRL LPS (FET); PARK LAMPS (FET); TURN; OUTAGE; TURN LAMPS (FET); LIN 05; LF HI BEAM (FET); VBATT 1 BUS; HEADLAMP; DRL; ASSEMBLY; BEAM; GND; PARK

Hot at all times

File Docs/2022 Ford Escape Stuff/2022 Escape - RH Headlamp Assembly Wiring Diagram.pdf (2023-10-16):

10/16/23, 11:55 AM | about:blank

## LED

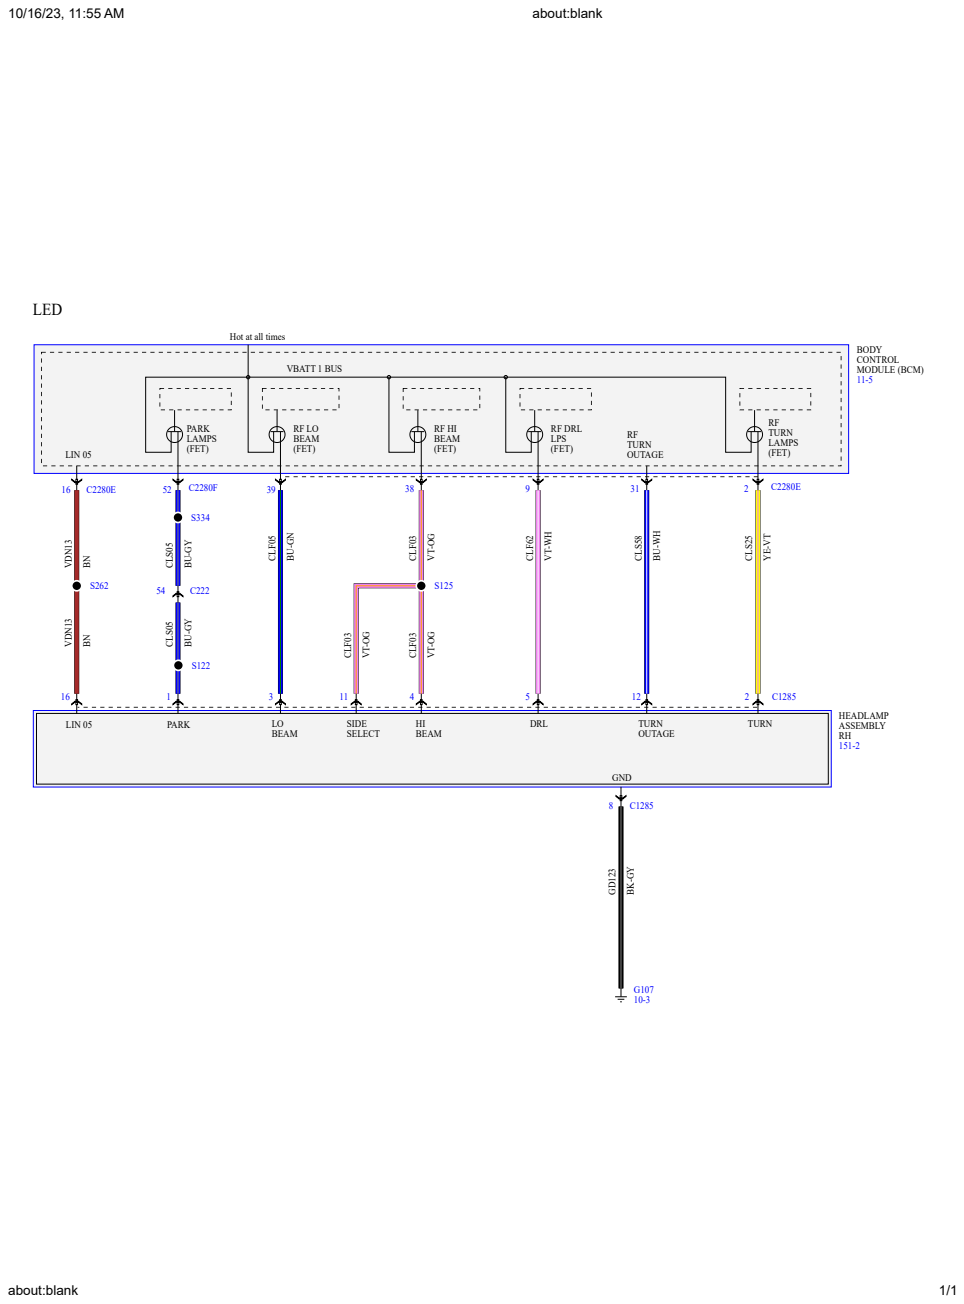
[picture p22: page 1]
about:blank; CLF05; VDN13; CLF03 CLF03; CLF03; CLS58; CLF62; CLS25; CLS05; MODULE (BCM); CONTROL; BODY; RF LO BEAM (FET); RF DRL LPS (FET); PARK LAMPS (FET); TURN; OUTAGE; TURN LAMPS (FET); LIN 05; RF HI BEAM (FET); VBATT 1 BUS; HEADLAMP; DRL; ASSEMBLY; BEAM; SELECT; PARK; SIDE; GND

Hot at all times

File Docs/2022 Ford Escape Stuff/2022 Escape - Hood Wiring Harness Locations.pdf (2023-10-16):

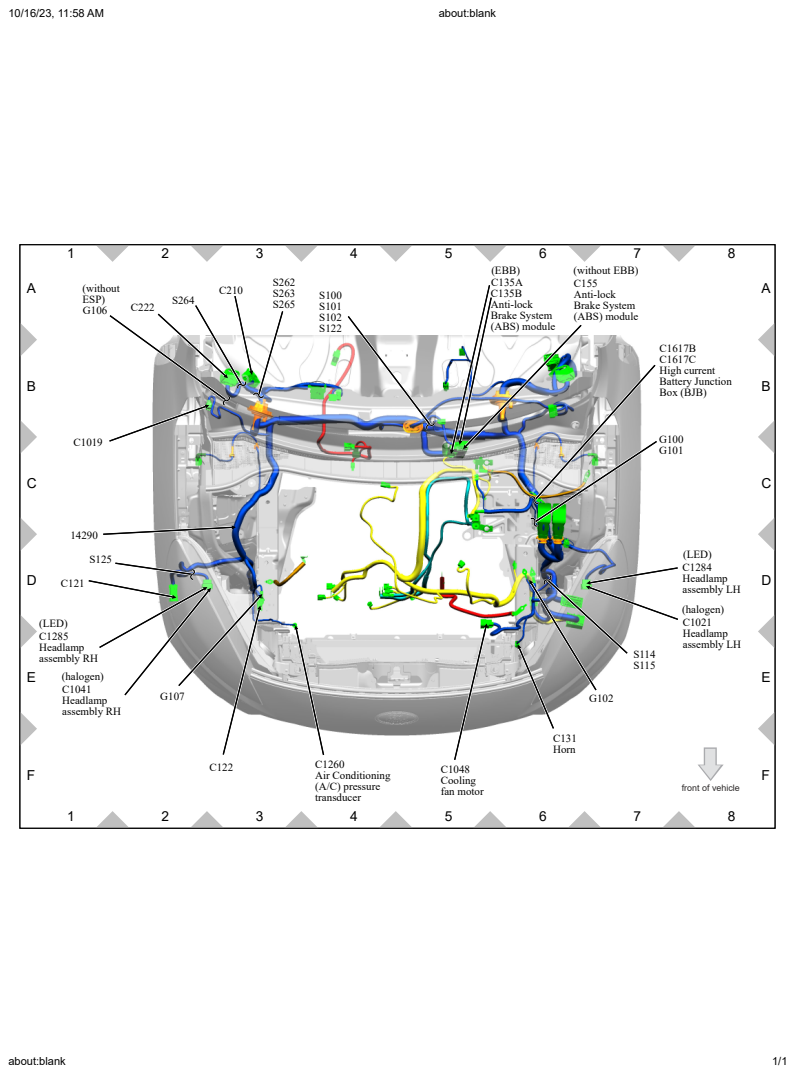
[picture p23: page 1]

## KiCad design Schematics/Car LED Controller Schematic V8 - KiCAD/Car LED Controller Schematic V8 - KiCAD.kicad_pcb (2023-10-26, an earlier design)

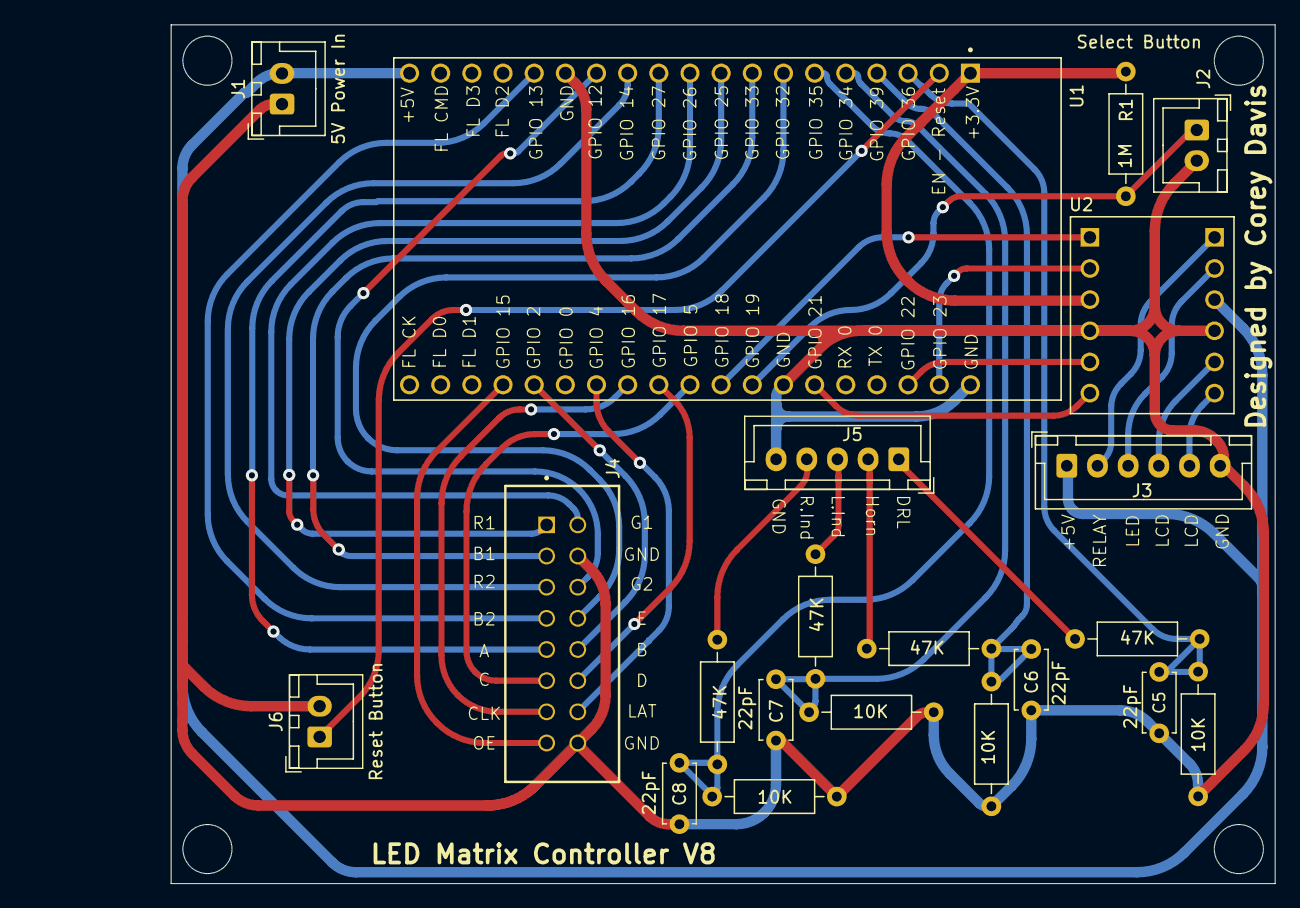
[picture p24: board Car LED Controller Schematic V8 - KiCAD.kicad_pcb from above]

Board: 2 copper layers, 90.0 x 70.0 mm, 21 parts (0 on the bottom side), 35 nets.

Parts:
C5, C6, C7, C8: 22pF; C_Disc_D4.7mm_W2.5mm_P5.00mm
J1: 5V Power In; JST_XH_B2B-XH-A_1x02_P2.50mm_Vertical
J2: Select Button; JST_XH_B2B-XH-A_1x02_P2.50mm_Vertical
J3: LCD, Relay, LED Signal; JST_XH_B6B-XH-A_1x06_P2.50mm_Vertical
J4: ZSS-108-01-F-D-506; SAMTEC_ZSS-108-01-F-D-506
J5: DRL, Horn Sense; JST_XH_B5B-XH-A_1x05_P2.50mm_Vertical
J6: Reset Button; JST_XH_B2B-XH-A_1x02_P2.50mm_Vertical
R1: 1M; R_Axial_DIN0207_L6.3mm_D2.5mm_P10.16mm_Horizontal
R10, R12, R14, R16: 47K; R_Axial_DIN0207_L6.3mm_D2.5mm_P10.16mm_Horizontal
R11, R13, R15, R17: 10K; R_Axial_DIN0207_L6.3mm_D2.5mm_P10.16mm_Horizontal
U1: ESP32-DEVKITC-32D; MODULE_ESP32-DEVKITC-32D
U2: BOB-12009; CONV_BOB-12009

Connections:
+3.3V: R1.1, U1.J2-1 (3V3), U2.LV
+5V: J1.2, J3.1 (+5V), U1.J2-19 (EXT_5V), U2.HV
GND: C5.2, C6.2, C7.2, C8.2, J1.1, J2.2, J3.6 (GND), J4.04 (GND), J4.16 (GND), J5.5 (GND), J6.2, R11.2, R13.2, R15.2, R17.2, U1.J2-14 (GND1), U1.J3-1 (GND3), U1.J3-7 (GND2), U2.GND_1 (GND), U2.GND_2 (GND)
unnamed: J2.1, R1.2, U1.J3-8 (IO19)
unnamed: J3.4 (LCD), U2.HV3
unnamed: J3.5 (LCD), U2.HV4
unnamed: J3.2 (LED), U2.HV1
unnamed: J3.3 (Relay), U2.HV2
unnamed: J4.09 (A), U1.J2-11 (IO27)
unnamed: J4.03 (B1), U1.J2-8 (IO33)
unnamed: J4.07 (B2), U1.J2-15 (IO13)
unnamed: J4.10 (B), U1.J3-15 (IO2)
unnamed: J4.11 (C), U1.J3-10 (IO5)
unnamed: J4.13 (CLK), U1.J3-12 (IO16)
unnamed: J4.12 (D), U1.J3-11 (IO17)
unnamed: J4.08 (E), U1.J2-7 (IO32)
unnamed: J4.02 (G1), U1.J2-10 (IO26)
unnamed: J4.06 (G2), U1.J2-13 (IO12)
unnamed: J4.14 (LAT), U1.J3-13 (IO4)
unnamed: J4.15 (OE), U1.J3-16 (IO15)
unnamed: J4.01 (R1), U1.J2-9 (IO25)
unnamed: J4.05 (R2), U1.J2-12 (IO14)
unnamed: J5.1 (DRL), R10.2
unnamed: J5.2 (Horn), R12.2
unnamed: J5.3 (Res), R14.2
unnamed: J5.4 (Res), R16.2
unnamed: J6.1, U1.J2-2 (EN)
unnamed: U1.J3-9 (IO18), U2.LV1
unnamed: U1.J3-6 (IO21), U2.LV4
unnamed: U1.J3-3 (IO22), U2.LV3
unnamed: U1.J3-2 (IO23), U2.LV2
unnamed: C7.1, R14.1, R15.1, U1.J2-5 (IO34)
unnamed: C8.1, R16.1, R17.1, U1.J2-6 (IO35)
unnamed: C6.1, R12.1, R13.1, U1.J2-4 (SENSOR_VN)
unnamed: C5.1, R10.1, R11.1, U1.J2-3 (SENSOR_VP)

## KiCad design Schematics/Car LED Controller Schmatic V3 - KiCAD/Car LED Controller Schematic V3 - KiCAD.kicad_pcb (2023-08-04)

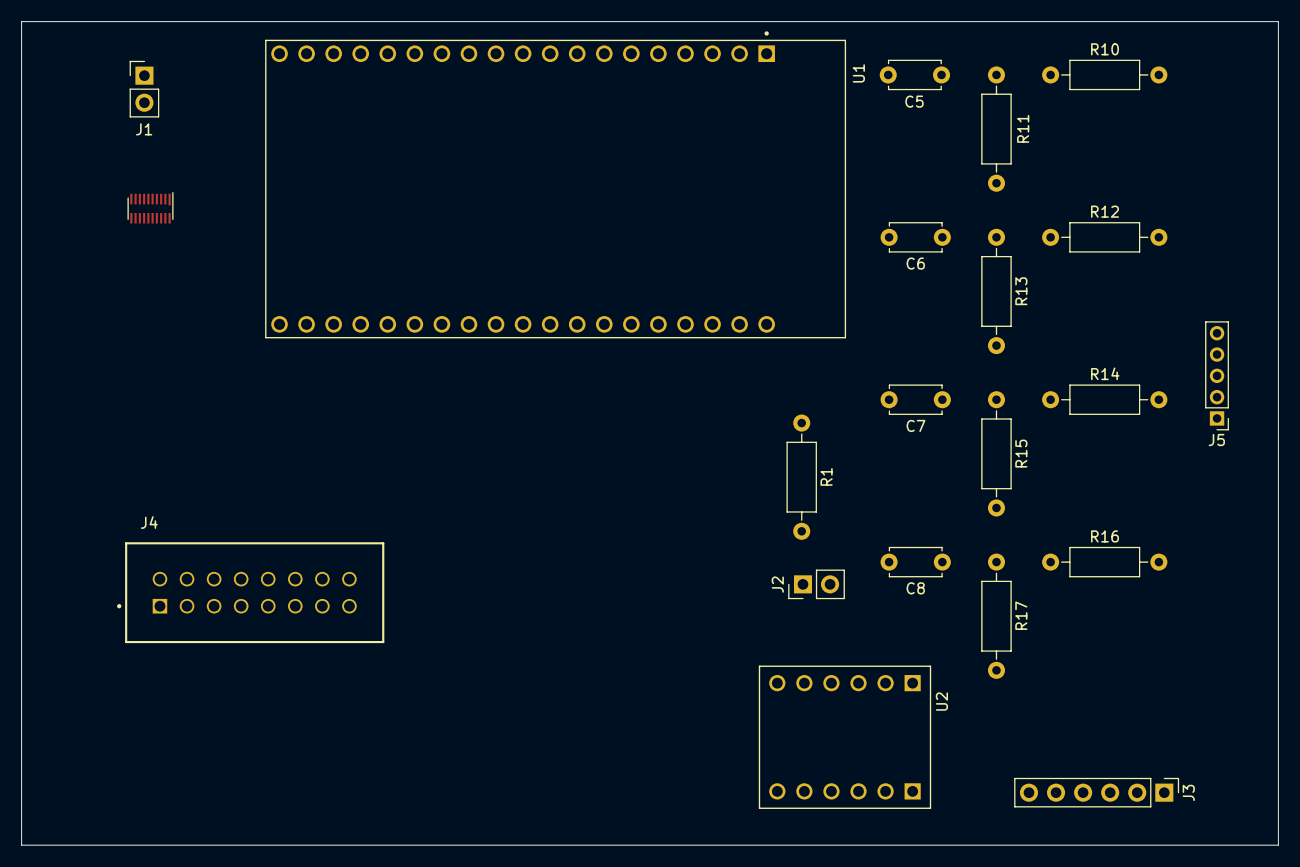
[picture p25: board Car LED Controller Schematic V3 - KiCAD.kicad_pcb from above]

Board: 2 copper layers, 118.0 x 77.3 mm, 22 parts (1 on the bottom side), 48 nets, no tracks yet.

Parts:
C5, C6, C7, C8: 22pF; C_Disc_D4.7mm_W2.5mm_P5.00mm
J1: 5V Power In; PinHeader_1x02_P2.54mm_Vertical
J2: Select Button; PinHeader_1x02_P2.54mm_Vertical
J3: LCD, Relay, LED Signal; PinHeader_1x06_P2.54mm_Vertical
J4: TSS-108-01-L-D; SAMTEC_TSS-108-01-L-D
J5: Conn_01x05_Pin; PinHeader_1x05_P2.00mm_Vertical
R1: 1M; R_Axial_DIN0207_L6.3mm_D2.5mm_P10.16mm_Horizontal
R10, R12, R14, R16: 47K; R_Axial_DIN0207_L6.3mm_D2.5mm_P10.16mm_Horizontal
R11, R13, R15, R17: 10K; R_Axial_DIN0207_L6.3mm_D2.5mm_P10.16mm_Horizontal
U1: ESP32-DEVKITC-32D; MODULE_ESP32-DEVKITC-32D
U2: BOB-12009; CONV_BOB-12009
U3, U4: TXB0108DQSR; USON-20_2x4mm_P0.4mm

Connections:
+3.3V: R1.1, U1.J2-1 (3V3), U2.LV, U3.5 (VCCA), U4.5 (VCCA)
+5V: J1.2, J3.1, U1.J2-19 (EXT_5V), U2.HV, U3.16 (VCCB), U4.16 (VCCB)
GND: C5.2, C6.2, C7.2, C8.2, J1.1, J2.2, J3.6, J4.04 (GND), J4.16 (GND), J5.1, R11.2, R13.2, R15.2, R17.2, U1.J2-14 (GND1), U1.J3-1 (GND3), U1.J3-7 (GND2), U2.GND_1 (GND), U2.GND_2 (GND), U3.6 (OE), U3.15 (GND), U4.6 (OE), U4.15 (GND)
unnamed: J2.1, R1.2, U1.J2-5 (IO34)
unnamed: J3.2, U2.HV1
unnamed: J3.3, U2.HV2
unnamed: J3.4, U2.HV3
unnamed: J3.5, U2.HV4
unnamed: J4.09 (A), U3.17 (B4)
unnamed: J4.03 (B1), U3.12 (B7)
unnamed: J4.07 (B2), U3.14 (B5)
unnamed: J4.10 (B), U4.17 (B4)
unnamed: J4.11 (C), U3.18 (B3)
unnamed: J4.13 (CLK), U3.19 (B2)
unnamed: J4.12 (D), U4.14 (B5)
unnamed: J4.08 (E), U4.18 (B3)
unnamed: J4.02 (G1), U4.20 (B1)
unnamed: J4.06 (G2), U4.19 (B2)
unnamed: J4.14 (LAT), U4.13 (B6)
unnamed: J4.15 (OE), U3.20 (B1)
unnamed: J4.01 (R1), U3.11 (B8)
unnamed: J4.05 (R2), U3.13 (B6)
unnamed: J5.2, R16.2
unnamed: J5.3, R14.2
unnamed: J5.4, R12.2
unnamed: J5.5, R10.2
unnamed: U1.J3-15 (IO2), U4.2 (A2)
unnamed: U1.J3-13 (IO4), U4.3 (A3)
unnamed: U1.J3-10 (IO5), U4.8 (A6)
unnamed: U1.J2-13 (IO12), U3.9 (A7)
unnamed: U1.J2-15 (IO13), U3.10 (A8)
unnamed: U1.J2-12 (IO14), U3.8 (A6)
unnamed: U1.J3-16 (IO15), U4.1 (A1)
unnamed: U1.J3-12 (IO16), U4.4 (A4)
unnamed: U1.J3-11 (IO17), U4.7 (A5)
unnamed: U1.J3-9 (IO18), U2.LV1
unnamed: C8.1, R16.1, R17.1, U1.J3-8 (IO19)
unnamed: U1.J3-6 (IO21), U2.LV4
unnamed: U1.J3-3 (IO22), U2.LV3
unnamed: U1.J3-2 (IO23), U2.LV2
unnamed: U1.J2-9 (IO25), U3.3 (A3)
unnamed: U1.J2-10 (IO26), U3.4 (A4)
unnamed: U1.J2-11 (IO27), U3.7 (A5)
unnamed: U1.J2-7 (IO32), U3.1 (A1)
unnamed: U1.J2-8 (IO33), U3.2 (A2)
unnamed: C7.1, R14.1, R15.1, U1.J2-6 (IO35)
unnamed: C6.1, R12.1, R13.1, U1.J2-4 (SENSOR_VN)
unnamed: C5.1, R10.1, R11.1, U1.J2-3 (SENSOR_VP)

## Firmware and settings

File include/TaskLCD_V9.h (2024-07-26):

#ifndef _TASKLCD_V9_H_
#define _TASKLCD_V9_H_


#include <stdio.h>
#include <Wire.h>
#include <hd44780.h>                       // main hd44780 header
#include <hd44780ioClass/hd44780_I2Cexp.h> // i2c expander i/o class header

//#ifdef __cplusplus
//extern "C" {
//#endif

//void taskLCDUpdates( void * pvParameters );
//void initTaskLCD();


// LCD column and row settings
#define LCD_COLS  16
#define LCD_ROWS  2 
#define LCD_UPDATE_INTERVAL 150   // How fast to update LCD in ms

class TaskLCD {
  public:
    void *taskLCDUpdates( void * pvParameters );
    void initTaskLCD();
    
    hd44780_I2Cexp lcd;               // Declare lcd object: auto locate & config exapander chip

};

extern TaskLCD curLCD;





#if LED_STRIP
//LED Strip
  #define NUM_LEDS  134   //161 leds is the lenght of the hood weather strip, 36 for the COB strip
  #define NUM_LEDS_HALF   (NUM_LEDS - 1) / 2    //Subtract 1 to calculate indexes
  #define LEDS_PER_PIXEL 1
  #define NUM_PIXELS (NUM_LEDS / LEDS_PER_PIXEL)
  #define NUM_PIXELS_HALF (NUM_PIXELS / 2)
  #define NUM_PIXELS_THIRD (NUM_PIXELS / 3)
  #define NUM_PIXELS_QUARTER (NUM_PIXELS / 4)
  #define NUM_PIXELS_FIFTH (NUM_PIXELS / 5)
  #define RGBW_STRIP false //for RGB Strips change to false
  #define RGBW_COLOR_ORDER NEO_GRBW //Change this to match the order of color for the LED Strip see NeoPixel library for definitions
  #define RGB_COLOR_ORDER NEO_RGB //Change this to match the order of color for the LED Strip see NeoPixel library for definitions
  #define FLASH_RATE int((80/120)*1000) //how many indicator flashes per minute as specifed by car manufacturer 
  #define msIND_DELAY  int(FLASH_RATE / NUM_PIXELS_HALF * 2 + 0.5) //Number of ms Indicator LED stays on for.
  #define msDELAY  int(400 / NUM_PIXELS + 0.5)   //Number of ms LED stays on for.
  #define numLOOPS      4   //Number of passes over entire LED strip

  #include <Adafruit_NeoPixel.h>

  #if RGBW_STRIP 
    #define cur_COLOR_ORDER RGBW_COLOR_ORDER
  #else
    #define cur_COLOR_ORDER RGB_COLOR_ORDER
  #endif

  extern Adafruit_NeoPixel leds(NUM_LEDS, LED_PIN, cur_COLOR_ORDER + NEO_KHZ800);

  #if RGBW_STRIP 
    //color definitions values, are expressed in rgbw format
    #define ANGRY_COLOR     leds.Color( 255, 60,  0,   0 )     //Amber
    #define DEFAULT_COLOR   leds.Color( 251, 255, 141, 255 )     //White (Adjusted to match vehicle oem light color)
    #define LYFT_COLOR      leds.Color( 255,  0, 191,  0 )     //Magenta
    #define UBER_COLOR      leds.Color( 0,  255,  92,  0 )     //Seafoam Green
    #define BRIGHTCOLOR   leds.Color( 255, 255, 255, 255 )     //Full White
    #define DIMCOLOR      leds.Color(  50,  50,  50,  50 )     //Dim White
    #define OFFCOLOR      leds.Color(   0,   0,   0,   0 )     //Off
  #else
    //color definitions values, are expressed in rgb format
    #define ANGRY_COLOR     leds.Color( 255, 60,  0   )     //Amber
    #define DEFAULT_COLOR   leds.Color( 251, 255, 141 )     //White (Adjusted to match vehicle oem light color)
    #define LYFT_COLOR      leds.Color( 255, 0,   191 )     //Magenta
    #define UBER_COLOR      leds.Color( 0,  255,  92  )     //Seafoam Green
    #define BRIGHTCOLOR   leds.Color( 251,  255,  141 )     //Full White
    #define DIMCOLOR      leds.Color( 125,  127,  70  )     //Dim White
    #define OFFCOLOR      leds.Color(   0,   0,   0   )     //Off
  #endif
#endif


#endif // _TASKLCD_V9_H_

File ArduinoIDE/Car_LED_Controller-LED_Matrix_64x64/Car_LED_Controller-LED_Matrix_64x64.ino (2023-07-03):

/*-----------------------------------------------------------------
    Program:        car_led_controller
    Description:    Controls LED strip behavior based on various 
                    Inputs such as, drl, headlights, horn, and button
		                activity. This is for the esp32 38pin device
    Date:           5/18/2023
    Version:        1
    Authors:        Yves Avady
    Contriburtors:   Corey Davis, Jim Edmonds 
-----------------------------------------------------------------*/
#include <stdio.h>
#include <Adafruit_NeoPixel.h>
#include <ezButton.h> 
#include <Wire.h>
#include <hd44780.h>                       // main hd44780 header
#include <hd44780ioClass/hd44780_I2Cexp.h> // i2c expander i/o class header
#include <driver/adc.h>
#include <esp_adc_cal.h>
#include <ESP32-HUB75-MatrixPanel-I2S-DMA.h>
#include <logos.h>  //uber and luft logos

//Build Configuration Options
#define PROD  //Enable serial output for debug, change to DEBUG, to disable change to PROD
#define SCREENTEST_OFF //To enable the boot up screen test, change to SCREENTEST_ON, to disable change to SCREENTEST_OFF
#define NO_LED_MATRIX //for future development
#define NO_LED_STRIP //for future development
#define NUM_MODES 2

//MatrixPanel_I2S_DMA dma_display;
MatrixPanel_I2S_DMA *dma_display = nullptr;

//LED Martrix pin section
//This is configured using a P2 64x64 LED Matrix, which has an E pin.
#define R1_PIN  32
#define G1_PIN  33
#define B1_PIN  25
#define R2_PIN  26
#define G2_PIN  27
#define B2_PIN  14
#define A_PIN   13
#define B_PIN   15 
#define C_PIN   2
#define D_PIN   4
#define E_PIN   12  
#define LAT_PIN 17
#define OE_PIN  5
#define CLK_PIN 16

// Pins to device mapping
#define RELAY_PIN_1 18        // D18 => In1 Relay
#define RELAY_PIN_2 19        // D19 => In2 Relay
#define LED_PIN     23        // D23 => LED Controller Signal
#define DRL_PIN     ADC1_CHANNEL_0        // Pin 33 => DRL Sense
#define HORN_PIN    ADC1_CHANNEL_3       // Pin 32 => Horn Sense
ezButton modeButton(34);  // create ezButton object that attach to pin 34;
//#define PK_L_PIN        35        // D35 => Parking Lights Sense (Reserved) 
//#define HIBM_PIN        33        // D33 => HiBeam Sense (Reserved)

// set the LCD address to 0x27 for a 16 chars and 2 line display
#define LCD_COLS  16
#define LCD_ROWS  2 
#define LCD_UPDATE_INTERVAL 150   // How fast to update LCD in ms
hd44780_I2Cexp lcd;               // Declare lcd object: auto locate & config exapander chip

//LED Controller Section
#define NUM_LEDS        193  //193 leds is the lenght of the hood weather strip including 15 leds on each side to show thru the headlights.
#define NUM_LEDS_HALF   (NUM_LEDS - 1) / 2    // Subtract 1 to calculate indexes
Adafruit_NeoPixel leds(NUM_LEDS, LED_PIN, NEO_GRBW + NEO_KHZ800);

//Define lcd and led brightness
#define MAX_BRIGHTNESS  255
#define MIN_BRIGHTNESS  63
#define MED_BRIGHTNESS  127

//color definitions values, are expressed in rgbw format
#define ANGRY_COLOR     leds.Color( 255, 60,  0,   0 )     //Amber
#define DEFAULT_COLOR   leds.Color( 0,  0,  0,   255 )     //White
#define LYFT_COLOR      leds.Color( 255,  0, 191,  0 )     //Magenta
#define UBER_COLOR      leds.Color( 0,  255,  92,  0 )     //Seafoam Green
#define BRIGHTCOLOR   leds.Color( 255, 255, 255, 255 )     //Full White
#define DIMCOLOR      leds.Color(  50,  50,  50,  50 )     //Dim White
#define OFFCOLOR      leds.Color(   0,   0,   0,   0 )     //Off

#define RELAY_ON LOW
#define RELAY_OFF HIGH

#define NUM_SAMPLES     10              // number of analog samples to take per reading
#define R1              47.0            // Resistor 1 value of voltage divider
#define R2              10.0            // Resistor 2 value of voltage divider
#define VOLT_DIV_FACTOR (R1+R2)/R2      //voltage divider factor
static esp_adc_cal_characteristics_t ADC1_Characteristics;

#define VOLT_BUF        1
#define HI_VOLT         12
#define LO_VOLT         2

// Startup Configuration (Constants)
#define msDELAY       0   //Number of ms LED stays on for.
#define numLOOPS      4   //Humber of passes over entire LED strip

#define DEBOUNCE_TIME 75 // the debounce time in millisecond, increase this time if it still chatters

//LED Matrix Initialization
#define PANEL_RES_X 64  // Number of pixels wide of each INDIVIDUAL panel module.
#define PANEL_RES_Y 64  // Number of pixels tall of each INDIVIDUAL panel module.
#define PANEL_CHAIN 1   // Total number of panels chained one to another

//LED Maxtrix color initialization
uint16_t myBlack = dma_display->color565(0, 0, 0);
uint16_t myWHITE = dma_display->color565(255, 255, 255);
uint16_t myRED = dma_display->color565(255, 0, 0);
uint16_t myGREEN = dma_display->color565(0, 255, 0);
uint16_t myBLUE = dma_display->color565(0, 0, 255);
uint16_t myMAGENTA = dma_display->color565(255, 0, 191);

static float curDRL    = 0.0f;
static float curHorn   = 0.0f;
//static double curPkL    = 0.0;
//static double curHiBeam = 0.0;

void drawLyftLogo(){  
dma_display->fillScreen(myBlack);
  for (int xPos = 0; xPos < 64; xPos++ ) {
    for (int yPos = 0; yPos < 64; yPos++ ) {
      long Pos = (xPos + yPos * 64) * 4;
      uint8_t red = LYFT_LOGO[Pos + 2] ? 255 : 255;
      uint8_t green = LYFT_LOGO[Pos + 1] ? 0 : 255;
      uint8_t blue = LYFT_LOGO[Pos] ? 191 : 255;
      dma_display->drawPixel(xPos, yPos, dma_display->color565(red, green, blue));
    }
  }
}

void drawUberLogo(){  
dma_display->fillScreen(myBlack);
  for (int xPos = 0; xPos < 64; xPos++ ) {
    for (int yPos = 0; yPos < 64; yPos++ ) {
      long Pos = (xPos + yPos * 64) * 4;
      uint8_t red = UBER_LOGO[Pos + 2] ? 0 : 255;
      uint8_t green = UBER_LOGO[Pos + 1] ? 0 : 255;
      uint8_t blue = UBER_LOGO[Pos] ? 0 : 255;
      dma_display->drawPixel(xPos, yPos, dma_display->color565(red, green, blue));
    }
  }
}

class cModes {
  public:
    int curColor;
    String txtColor;
    bool isUberDisplayed;
    bool isLyftDisplayed;

    void Increment () {
      if (modeButton.getCount() > NUM_MODES) { modeButton.resetCount(); }
      switch (modeButton.getCount()) {
        case 1:
            if (isLyftDisplayed == true) {isLyftDisplayed = false;}
            curColor = UBER_COLOR;
            txtColor = "UBER"; 
            #ifdef DEBUG         
            Serial.println("LED color set to Uber Mode color (Seafoam Green)");
            #endif
            if (txtColor == "UBER" && isUberDisplayed == false){
              drawUberLogo();
              isUberDisplayed = true;
            } 
            break;
        case 2:
            if (isUberDisplayed == true) {isUberDisplayed = false;}
            curColor = LYFT_COLOR;
            txtColor = "LYFT";
            #ifdef DEBUG
            Serial.println("LED color set to Lyft Mode color (Magenta)");
            #endif
            if (txtColor == "LYFT" && isLyftDisplayed == false){
              drawLyftLogo();
              isLyftDisplayed = true;
            }
            break;
        default:
            curColor = DEFAULT_COLOR;
            txtColor = "WHIT";
            #ifdef DEBUG
            Serial.println("LED color set to Default Mode color (White)");
            #endif
            dma_display->fillScreen(myBlack);
            isLyftDisplayed = false;
            isUberDisplayed = false;
            break;
      }
    }

    void Init() {
      curColor = DEFAULT_COLOR;
      txtColor = "WHIT";
      delay(50);
      modeButton.loop();      // MUST call the loop() function first
      modeButton.getCount();
      modeButton.resetCount();
    }
};
cModes curMode;

bool firstLoop = true;

void taskLCDUpdates( void * pvParameters ){
  char tmpMessage[16];
  lcd.clear();    //clear the display and home the cursor
  sprintf(tmpMessage, "MODE DRL   Horn "); 
  lcd.setCursor(0,0); //move cursor to 1st line on display
  lcd.print(tmpMessage);
  delay(50); 

  while(true){
    if (curHorn > VOLT_BUF) {
      sprintf(tmpMessage, "HORN %04.1fV %04.1fV", curDRL, curHorn); 
    } else {
      sprintf(tmpMessage, "%s %04.1fV %04.1fV", curMode.txtColor, curDRL, curHorn);  
    }
    lcd.setCursor(0,1); //move cursor to 2nd line on display
    lcd.print(tmpMessage);
    delay(LCD_UPDATE_INTERVAL);
  }
}

void ledWave(uint32_t maxColor, uint32_t minColor, int msDelay, bool boolDirection) {
  int ledLeft = 0; int ledRight = 0;
  int offset;
  for (int i = 1; i <= NUM_LEDS_HALF; i++) {
    // Set current left and right LEDs based on the direction
    if (boolDirection) {                //Out 
      ledLeft = NUM_LEDS_HALF - i;
      offset = 1; 
    } else {                              //In
      ledLeft = i; 
      offset = -1;
    }
    ledRight = NUM_LEDS - ledLeft -1;
    leds.setPixelColor(ledLeft, maxColor);              leds.setPixelColor(ledRight, maxColor);
    leds.setPixelColor(ledLeft + offset, minColor);     leds.setPixelColor(ledRight - offset, minColor);
    if (msDelay) {
      delay(msDelay);
    }
    leds.show();
  }
}

void startupSequence() {
  // Loop 4 times
  //  1 - Towards center clear trail
  //  2 - Away from center clear trail
  //  3 - Towards center remain partial brightness
  //  4 - Away from center remain full brightness 
  uint32_t curDimColor = OFFCOLOR;
  for (int i = 0; i < numLOOPS; i++){
    switch(i) {
      case 2:
        curDimColor = DIMCOLOR;
        break;
      case 3:
        curDimColor = BRIGHTCOLOR;
        break;
      default:
        curDimColor = OFFCOLOR;
    }
    // Perform the LED wave effect
    ledWave(BRIGHTCOLOR, curDimColor, msDELAY, i % 2);
  }

  // Turn DefaultSolid Color:
  leds.fill(DEFAULT_COLOR);
  leds.show();
}

float Abs(float val) {
  if (val > 0) { return val; }
  else { return -val; }
}

void screentest() {

  // fix the screen with green
  dma_display->fillRect(0, 0, dma_display->width(), dma_display->height(), dma_display->color444(0, 15, 0));
  delay(100);

  // draw a box in yellow
  dma_display->drawRect(0, 0, dma_display->width(), dma_display->height(), dma_display->color444(15, 15, 0));
  delay(100);

  // draw an 'X' in red
  dma_display->drawLine(0, 0, dma_display->width() - 1, dma_display->height() - 1, dma_display->color444(15, 0, 0));
  dma_display->drawLine(dma_display->width() - 1, 0, 0, dma_display->height() - 1, dma_display->color444(15, 0, 0));
  delay(100);

  // draw a blue circle
  dma_display->drawCircle(10, 10, 10, dma_display->color444(0, 0, 15));
  delay(100);

  // fill a violet circle
  dma_display->fillCircle(40, 21, 10, dma_display->color444(15, 0, 15));
  delay(100);

  // fill the screen with 'black'
  dma_display->fillScreen(dma_display->color444(0, 0, 0));

}



void setup()
{
  #ifdef DEBUG
    Serial.begin(115200);   // serial monitor for debugging
  #endif
  
  delay(250); // power-up safety delay
    
  //setup the button
  modeButton.setDebounceTime(DEBOUNCE_TIME);  // set debounce time to 50 milliseconds    
  modeButton.setCountMode(COUNT_RISING);      // set a rising count for button

  // set up the LCD:
  lcd.begin(LCD_COLS, LCD_ROWS); //begin() will automatically turn on the backlight
  lcd.clear();            //clear the display  
  lcd.home();             //move cursor to 1st line on display
  lcd.print("LOADING");   
  lcd.setCursor(0,1);     //move cursor to 2nd line on display
  lcd.print("PLEASE WAIT");   

  // Set pins as an input or output pin
  pinMode(RELAY_PIN_1, OUTPUT);
  pinMode(RELAY_PIN_2, OUTPUT);
  pinMode(LED_PIN, OUTPUT);
  pinMode(DRL_PIN, INPUT);
  pinMode(HORN_PIN, INPUT);
  //pinMode(PK_L_PIN, INPUT);
  //pinMode(HIBM_PIN, INPUT);

  // Configure ADC
  esp_adc_cal_characterize(ADC_UNIT_1, ADC_ATTEN_DB_11, ADC_WIDTH_BIT_12, 0, &ADC1_Characteristics);
  ESP_ERROR_CHECK(adc1_config_width(ADC_WIDTH_BIT_12));
  ESP_ERROR_CHECK(adc1_config_channel_atten(DRL_PIN, ADC_ATTEN_DB_11));
  ESP_ERROR_CHECK(adc1_config_channel_atten(HORN_PIN, ADC_ATTEN_DB_11));

  // LED MATRIX Module configuration
  HUB75_I2S_CFG::i2s_pins _pins={R1_PIN, G1_PIN, B1_PIN, R2_PIN, G2_PIN, B2_PIN, A_PIN, B_PIN, C_PIN, D_PIN, E_PIN, LAT_PIN, OE_PIN, CLK_PIN};
  HUB75_I2S_CFG mxconfig(
    PANEL_RES_X,  // module width
    PANEL_RES_Y,  // module height
    PANEL_CHAIN,   // Chain length
    _pins // pin mapping
  );

  //mxconfig.gpio.e = 12;
  mxconfig.clkphase = false;
  mxconfig.driver = HUB75_I2S_CFG::FM6124;

  // Display Setup
  dma_display = new MatrixPanel_I2S_DMA(mxconfig);
  dma_display->begin();
  dma_display->setBrightness8(MAX_BRIGHTNESS); //5-255 led matrix does not display using values lower than 5
  dma_display->clearScreen();
  dma_display->fillScreen(myWHITE);

  // Start LEDs
  digitalWrite(RELAY_PIN_1, RELAY_ON);    //Turn on relay to provide power for LEDs
  leds.begin();
  leds.show();
  leds.setBrightness(MAX_BRIGHTNESS);

  // Initiate startup lighting sequence
  startupSequence(); 

  #ifdef SCREENTEST_ON
  screentest();
  #endif

  // Create task on Core 1 to Update LCD
  xTaskCreatePinnedToCore(
    taskLCDUpdates,   /* Function to implement the task */
    "taskLCDUpdates", /* Name of the task */
    10000,            /* Stack size in words */
    NULL,             /* Task input parameter */
    0,                /* Priority of the task */
    NULL,             /* Task handle. */
    1);               /* Core where the task should run */
}

void loop()
{
  static int    curSample = 1;
  static bool   RelayPin1State = false;

  curDRL += esp_adc_cal_raw_to_voltage(adc1_get_raw(DRL_PIN), &ADC1_Characteristics);
  curHorn += esp_adc_cal_raw_to_voltage(adc1_get_raw(HORN_PIN), &ADC1_Characteristics);
  //curPkL += analogRead(PK_L_PIN);
  //curHiBeam += analogRead(HIBM_PIN);
  curSample++;

 #ifdef DEBUG
  Serial.print("Horn Voltage:"); Serial.println(curHorn);
  Serial.print("DRL Voltage:"); Serial.println(curDRL);
  Serial.print("Current Sample Number:"); Serial.println(curSample);
  #endif

  modeButton.loop();      // MUST call the loop() function first
  #ifdef DEBUG
  Serial.print("Mode Select Button State:");  Serial.println(modeButton.getState());
  #endif
  if (firstLoop) {
    curMode.Init();
    firstLoop = false;
  } else {
    curMode.Increment();
  }

  if (curSample > NUM_SAMPLES){
    // Adjust voltages
    curDRL *= VOLT_DIV_FACTOR / NUM_SAMPLES / 1000;
    curHorn *= VOLT_DIV_FACTOR / NUM_SAMPLES / 1000;
    //curPkL *= VOLT_ADJ;
    //curHiBeam *= VOLT_ADJ;

    if (Abs(curDRL - LO_VOLT) < VOLT_BUF) {
      if (!RelayPin1State) {
        RelayPin1State = true;
        //turn on relay1
        digitalWrite(RELAY_PIN_1, RELAY_ON);
      }
      leds.setBrightness(MIN_BRIGHTNESS);
      dma_display->setBrightness8(MIN_BRIGHTNESS);
      #ifdef DEBUG
      Serial.println("DRL Brightness level LOW");
      #endif
    } else if (curDRL > (HI_VOLT - VOLT_BUF)) {
      if (!RelayPin1State) {
        RelayPin1State = true;
        //turn on relay1
        digitalWrite(RELAY_PIN_1, RELAY_ON);
      }
      leds.setBrightness(MAX_BRIGHTNESS);
      dma_display->setBrightness8(MAX_BRIGHTNESS);
      #ifdef DEBUG
      Serial.println("DRL Brightness level MAX");
      #endif
    } else if (curDRL < VOLT_BUF) {
      leds.setBrightness(0);
      if (RelayPin1State) {
        RelayPin1State = false;
        //turn off relay1
        digitalWrite(RELAY_PIN_1, RELAY_OFF);
        dma_display->setBrightness8(0);
      }
      #ifdef DEBUG
      Serial.println("DRL Brightness level OFF");
      #endif
    }

    if (curHorn > VOLT_BUF) {
      leds.fill(ANGRY_COLOR);  
    } else {
      leds.fill(curMode.curColor);  
    }

    leds.show();                      //<--- May not be needed
    
    curSample = 1;
    curDRL = 0;
    curHorn = 0;
    //curPkL = 0;
    //curHiBeam = 0;
  }
}

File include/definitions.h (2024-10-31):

#ifndef _DEFINITIONS_H_
#define _DEFINITIONS_H_

//Build Configuration Options
  #define DEBUG false      //Enable serial output for debug, change to "false" to disable
  #define SCREENTEST false  //To enable the boot up screen test, change to "true", to disable change to "false"
  #define LED_MATRIX false   //Set to "true" if you want to use a 64x64 LED Matrix, "false" to disable
  #define LED_STRIP false   //Set to "true" if you want to use the led strip, "false" to disable
  #define LCD_DISPLAY true   //Set to "true" if you want to use the LCD Charcxv acter Display, "false" to disable
  #define NUM_MODES 2       //How many modes will the mode button handle (2 for Uber and Lyft signs)
  #define SHOW_VOLTAGES_LCD true //Set to "true" to display voltages on the LCD, "false" to disable

// Pins to device mapping
  #define RELAY_PIN_1 18                // Pin 18 => In1 Relay
  #define LED_PIN     23                // Pin 23 => LED Controller Signal
  #define DRL_PIN     ADC1_CHANNEL_0    // Pin 39 => DRL Sense

  #define MODE_PIN	  19  // Pin 19 +> Mode selection
  #define HORN_PIN    39  // Pin 39 => Horn Sense
  #define IND_L_PIN   34  // Pin 34 => Left Indicator 
  #define IND_R_PIN   35  // Pin 35 => Right Indicator 

  #define DEBOUNCE_TIME 100

  //Define lcd and led brightness
  #define MAX_BRIGHTNESS  255
  #define MIN_BRIGHTNESS  63
  #define MED_BRIGHTNESS  127

  #define RELAY_ON LOW
  #define RELAY_OFF HIGH

  #define NUM_SAMPLES     50              // number of analog samples to take per reading
  #define R1              47.0            // Resistor 1 value of voltage divider
  #define R2              10.0            // Resistor 2 value of voltage divider
  #define VOLT_DIV_FACTOR (R1+R2)/R2      //voltage divider factor
  #define RESISTOR_DIODE_OFFSET 0.3       //voltage drop across the diode
  #define GRND_OFFSET 0.8
  //static esp_adc_cal_characteristics_t ADC1_Characteristics;

  #define VOLT_BUF        1
  #define HI_VOLT         6
  #define LO_VOLT         2
  
//#ifndef
  //#define CONFIG_ESP_INT_WDT_TIMEOUT_MS 5000

#endif //_DEFINITIONS_H

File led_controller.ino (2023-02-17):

/*-----------------------------------------------------------------
    Program:        car_led_controller

    Description:    Controls LED strip behavior based on various 
                    Inputs such as, drl, headlights, horn, and button
		    activity

    Date:           Added when finalized to production (2/6/2023)

    Authors:         Corey Davis, Yves Avady, Jim Edmonds
-----------------------------------------------------------------*/
#include <FastLED.h>
#include <LiquidCrystal.h>

// Pins to device mapping
#define RELAY_PIN_1     2         // D2 => In1 Relay
#define RELAY_PIN_2     3         // D3 => In2 Relay
#define LED_PIN         11        // D12 => LED Controller Signal
#define DRL_PIN         A5        // A2 => DRL Sense
#define PK_L_PIN        A4        // A3 => Parking Lights Sense 
#define HORN_PIN        A3        // A4 => Horn Sense
#define HIBM_PIN        A2        // A5 => HiBeam Sense

// initialize the LCD with the interface pins
LiquidCrystal lcd(9, 8, 7, 6, 5, 4);

//LED Controller Section
#define LED_TYPE        WS2811
#define NUM_LEDS        30
#define NUM_LEDS_HALF   NUM_LEDS / 2
#define NUM_LEDS_ODD    NUM_LEDS % 2
#define COLOR_ORDER     BRG
#define COLOR_TEMP      UncorrectedTemperature
CRGBArray<NUM_LEDS> leds;

#define MAX_BRIGHTNESS  255
#define MIN_BRIGHTNESS  95
#define MED_BRIGHTNESS  191

#define ANGRY_COLOR     CRGB(255,69,0)      //Orange
#define DEFAULT_COLOR   CRGB(255,255,255)   //White
#define LYFT_COLOR      CRGB(255,0,255)     //Magenta
#define UBER_COLOR      CRGB(255,165,0)     //Cyan

#define RELAY_ON LOW
#define RELAY_OFF HIGH

#define NUM_SAMPLES     10        // number of analog samples to take per reading
#define REF_VOLTAGE     5.09      // Reference Voltage
#define VOLT_DIV_FACTOR 22.368         //voltage divider factor
// voltage multiplied by 22 when using voltage divider that
// divides by 22. 22.368 is the calibrated voltage divider
const float VOLT_ADJ = REF_VOLTAGE * VOLT_DIV_FACTOR / 1024 / NUM_SAMPLES;

#define VOLT_BUF        2
#define HI_VOLT         12
#define LO_VOLT         4

void setup()
{
  // set up the LCD:
  lcd.begin(16, 2); //init lcd col and row
  lcd.clear();      //clear lcd screen
  
  lcd.home(); //move cursor to 1st line on display
  lcd.print(F("Loading..."));   
  lcd.setCursor(0,1); //move cursor to 2nd line on display
  lcd.print(F("Please Wait!"));   

  //Serial.begin(9600);   // serial monitor for debugging
  delay(250);           // power-up safety delay


  // Set pins as an input or output pin
  pinMode(RELAY_PIN_1, OUTPUT);
  pinMode(RELAY_PIN_2, OUTPUT);
  pinMode(LED_PIN, OUTPUT);
  pinMode(DRL_PIN, INPUT);
  pinMode(PK_L_PIN, INPUT);
  pinMode(HORN_PIN, INPUT);
  pinMode(HIBM_PIN, INPUT);

  // Start LEDs
  FastLED.addLeds<LED_TYPE, LED_PIN, COLOR_ORDER>(leds, NUM_LEDS).setCorrection(TypicalSMD5050);
  FastLED.setBrightness(MAX_BRIGHTNESS);
  FastLED.setTemperature(COLOR_TEMP);

  // Initiate startup lighting sequence
  startupSequence();
  lcd.clear();  //clear lcd screen
  lcd.autoscroll(); //enable scrolling on long lines
}

void loop()
{
  static int curMode = 1;
  static int curSample = 1;
  static float curDRL = 0;
  static float curPkL = 0;
  static float curHorn = 0;
  static float curHiBeam = 0;
  static bool RelayPin1State = false;

  curDRL += analogRead(DRL_PIN);
  curPkL += analogRead(PK_L_PIN);
  curHorn += analogRead(HORN_PIN);
  curHiBeam += analogRead(HIBM_PIN);
  curSample++;

  if (curSample > NUM_SAMPLES){
    curDRL *= VOLT_ADJ;
    curPkL *= VOLT_ADJ;
    curHorn *= VOLT_ADJ;
    curHiBeam *= VOLT_ADJ;
    curSample = 1;

    lcd.clear();    //clear lcd screen
    lcd.home();     //move cursor to 1st line on display
    lcd.print(F("DRL: "));   lcd.print(curDRL);    lcd.print(F("V   "));
    lcd.print(F("PkL: "));   lcd.print(curPkL);    lcd.print(F("V   "));
    lcd.print(F("Hrn: "));   lcd.print(curHorn);   lcd.print(F("V   "));
    lcd.print(F("HiBm: "));  lcd.print(curHiBeam); lcd.print(F("V   "));
     
    //Serial.print("Voltage of HIBM = ");   Serial.print(curHiBeam);    Serial.println ("V");
    //Serial.print("Voltage of Horn = ");   Serial.print(curHorn);      Serial.println ("V");
    //Serial.print("Voltage of PK_L = ");   Serial.print(curPkL);       Serial.println ("V");
    //Serial.print("Voltage of DRL = ");    Serial.print(curDRL);       Serial.println ("V");

    if (Abs(curDRL - LO_VOLT) < VOLT_BUF) {
      if (!RelayPin1State) {
        RelayPin1State = true;
        //turn on relay1
        //Serial.print("Turning on Relay 1 because DRL is: ");  Serial.print(curDRL);   Serial.println ("V");      
        digitalWrite(RELAY_PIN_1, RELAY_ON);
      }
      FastLED.setBrightness(MIN_BRIGHTNESS); //set low brightness
      FastLED.show();
      //Serial.println("DRL Brightness level LOW");
    } else if (curDRL > (HI_VOLT - VOLT_BUF)) {
      if (!RelayPin1State) {
        RelayPin1State = true;
        //turn on relay1
        //Serial.print("Turning on Relay 1 because DRL is: ");  Serial.print(curDRL);   Serial.println ("V");      
        digitalWrite(RELAY_PIN_1, RELAY_ON);
      }
      FastLED.setBrightness(MAX_BRIGHTNESS); //set max brightness
      FastLED.show();
      //Serial.println("DRL Brightness level MAX");
    } else if (curDRL < VOLT_BUF) {
      if (RelayPin1State) {
        RelayPin1State = false;
        //turn off relay1
        //Serial.print("Turning off Relay 1 because DRL is: ");  Serial.print(curDRL);   Serial.println ("V");      
        digitalWrite(RELAY_PIN_1, RELAY_OFF);
      }
      FastLED.setBrightness(0); //turn off lights
      FastLED.show();
      //Serial.println("DRL Brightness level OFF");
    }

    if (curHorn > (HI_VOLT - VOLT_BUF)) {
      fill_solid(leds, NUM_LEDS, ANGRY_COLOR);  
      lcd.setCursor(0,1); //move cursor to 2nd line on display
      lcd.print(F("Color: Orange"));   
      //Serial.println("LED color set to Horn color (orange)");
    } else {
      fill_solid(leds, NUM_LEDS, DEFAULT_COLOR);  
      lcd.setCursor(0,1); //move cursor to 2nd line on display
      lcd.print(F("Color: White"));   
      //Serial.println("LED color set to Default color (white)");
    }

    curDRL = 0;
    curPkL = 0;
    curHorn = 0;
    curHiBeam = 0;

    FastLED.delay(100); //Delay to prevent LCD flashing
  }
}
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

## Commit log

2023-02-07 Changes necessary to make arduino ide happy
2023-02-07 fixed serial print stements
2023-02-10 Roll led_strip_movement into main codebase
2023-02-14 VSCode Arduino IDE integrations
2023-02-15 fixed formatting and a few incorrect comments
    [led_controller.ino]
2023-02-16 fix horn color return
    [led_controller.ino]
2023-02-16 Fix mode change code
    [Uber-Lyft-Mode.ino]
2023-02-17 Remove Serial Print statements
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2023-02-17 Adding Fritzng Schematic parts for the hardware
    [Car LED Controller.fzz]
2023-02-17 updating breadboard
    [Car LED Controller.fzz]
2023-02-18 bb update
    [Car LED Controller.fzz]
2023-02-19 Splitting code for ESP32 and Arduino UNO
    [Car LED Controller.fzz, Car LED Controller1.fzz]
2023-02-21 fixed pins and comments
    [esp32-test_led_lcd.ino]
2023-02-21 fixed pin assign
2023-02-21 print bug fix
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2023-02-21 fix voltage calculation
2023-02-21 fix 0 voltage bug
2023-02-23 Making it actually work with the correct HW setup
    [Neopixel_RGBW_Strip_Test.ino]
2023-02-23 Found out that pin 12 is a bootsrapping pin
2023-02-24 Update to new led library
2023-02-24 fix voltage
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2023-02-24 tune voltage and color
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2023-02-27 adding values to make it work with my esp32
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2023-02-27 fixing resistor values
2023-02-27 fix print
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2023-02-27 Fix ADC readings
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2023-03-05 revert cause i changed wrong file
    [Uber-Lyft-Mode.ino]
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2023-03-10 Updating breadboard to match prototype
    [Car LED Controller.fzz]
2023-03-17 updated schematic
    [Car LED Controller.fzz]
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2023-05-08 Add files via upload
    Help you figure out what pins to use
    [ESP32 Pinout Worksheet.ods]
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2023-05-14 Project Reorganization to platformio
    [ESP32 Pinout Worksheet.ods]
2023-05-15 adding more data
    [ESP32 Pinout Worksheet.ods]
2023-05-15 added ESP32 38 pinout
    [ESP32 Pinout Worksheet.ods]
2023-05-16 adding pinouts to spreadsheet
    [ESP32 Pinout Worksheet.ods]
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2023-07-23 adding kicad schematic, pcb, and libraries
    [Car LED Controller Schematic V4 - KiCAD.dsn, Car LED Controller Schematic V4 - KiCAD.kicad_pcb, Car LED Controller Schematic V4 - KiCAD.kicad_sch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]
2023-07-25 Yves Schematic
    [Control Board.kicad_pcb]
2023-07-25 cleanup of pcb
    [Control Board.kicad_pcb]
2023-07-25 pcb revisions
    [Car LED Controller Schematic V4 - KiCAD.dsn, Car LED Controller Schematic V5 - KiCAD.dsn, Car LED Controller Schematic V5 - KiCAD.kicad_pcb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]
2023-07-28 more pcb designs
    [Car LED Controller Schematic V4 - KiCAD.kicad_pcb, Car LED Controller Schematic V6 - KiCAD.kicad_pcb, Car LED Controller Schematic V8 - KiCAD.kicad_pcb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]
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2023-08-03 more pcb
    [Car LED Controller Schematic V8 - KiCAD.kicad_pcb, Car LED Controller Schematic V8 - KiCAD.kicad_sch, freerouting.dsn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]
2023-08-04 schematic with logic level converter
    [Car LED Controller Schematic V3.kicad_pcb, Car LED Controller Schematic V3.kicad_sch]
2023-08-21 adding esp32
    [Controller Enclosure v1.FCStd]
2023-08-21 updating pcbs
    [Car LED Controller Schematic V3 - KiCAD.kicad_pcb, Car LED Controller Schematic V3 - KiCAD.kicad_sch, Car LED Controller Schematic V3.kicad_pcb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]
2023-08-21 added pcb
    [Controller Enclosure v1.FCStd]
2023-08-21 adding models
    [Controller Enclosure v1.FCStd, DB25S564GTLF--3DModel-STEP-56544.STEP, SBH11-NBPC-D08-SM-BK.stp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]
2023-08-21 added second connector
    [Controller Enclosure v1.FCStd]
2023-08-21 added more details
    [Car LED Controller Schematic V8 - KiCAD.kicad_sch, Car LED Controller V2 - Jim.kicad_pcb, ESP32 Pinout Worksheet.ods]
2023-08-22 added resistor model
    [Controller Enclosure v1.FCStd, RES_AH_0.25W_350mil_0R_1%.STEP, RES_AH_0.25W_400mil_0R_1%.STEP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]
2023-08-22 added all remeining models
    [Controller Enclosure v1.FCStd, female_header_a-bl254-eg-g02d.stp, female_header_a-bl254-eg-g06d.stp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]
2023-08-28 update schmetic and pcb
    [Car LED Controller Schematic V8 - KiCAD.kicad_sch]
2023-08-29 fixed led matrix pinout
    [main.cpp]
2023-09-01 fixed DRC issues
    [Car LED Controller Schematic V8 - KiCAD.kicad_pcb]
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2023-10-11 added led pixel calculations, and rgb, rgbw define
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2023-10-16 Temporary fix for car behaviors
    [main.cpp]
2023-10-16 Documenting Car Behaviors
    [Ford Escape Headlamp behavior list.xlsx]
2023-10-17 adding additional Drl input and indicator function
    [Ford Escape Headlamp behavior list.xlsx]
2023-10-20 Added indicator and fixed drl variables
    [main.cpp]
2023-10-26 whole lotta fun
    [Car LED Controller Schematic V8 - KiCAD.kicad_pcb]
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2023-10-27 fix case sensitive stuff
2023-11-26 Adding more CAD and 3D Models
    [Car LED Controller Schematic V9 - KiCAD.kicad_pcb, Car LED Controller Schematic V9 - KiCAD.kicad_sch, Controller Enclosure v1-64x64 LED Matrix.stl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]
2023-11-28 PCB and Schematic updates
    [Car LED Controller Schematic V9 - KiCAD.kicad_sch]
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2023-12-07 Added the ability to remove the led matrix
2023-12-08 Create TaskLCD_V9.h
    Adding TaskLDC header file for V9 PCB
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2023-12-11 update indicator and hazard functions
    [Corey's Rear Enclosure2-Body.stl]
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2023-12-15 Fixed DRL monitor function (drl_mon())
    [main.cpp]
2023-12-15 hazard timing and spacing fixed
    [main.cpp]
2024-03-02 Update to schematic and PCBupdate
    [Car LED Controller Schematic V9 - KiCAD.kicad_sch, Corey's Rear Enclosure2.FCStd]
2024-03-02 updated pcb and schematic
    [Car LED Controller Schematic V9 - KiCAD.kicad_pcb, Car LED Controller Schematic V9 - KiCAD.kicad_sch]
2024-03-04 PCB upload to manufacturing
    [Car LED Controller Schematic V9 - KiCAD.kicad_pcb, Car LED Controller Schematic V9 - KiCAD.kicad_sch]
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2024-03-07 Removed BTN_INTERRUPT code, unsed and buggy
    [main.cpp]
2024-03-07 Moved Brightness, relay, and LED Martix actions to DRL_MON function - Working
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2024-03-08 Removed addition PCB Bdard Types and code cleanup
2024-03-08 correcting color values for white
    [main.cpp]
2024-03-09 Added the ability to disable the led strip and led matrix
2024-04-12 Cad edits
    [Corey's Rear Enclosure2.FCStd]
2024-04-12 Cad Fixes
    [Corey's Rear Enclosure2.FCStd]
2024-07-07 updates to model
    [Corey's Rear Enclosure2-LCD Cover.3mf, Corey's Rear Enclosure2-LCD Cover.stl, Corey's Rear Enclosure2.FCStd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]
2024-07-07 updating TaskLCD V9 issues
    [TaskLCD_V9.cpp, TaskLCD_V9.h, main.cpp]
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2024-07-23 fixed indicator funtions and detection
    [main.cpp]
2024-07-25 led variable fix
2024-10-04 adding linbus reading developemt
    [Processed_LIN_Bus_Frames - Indicator.csv]
2024-10-07 fixed break and sync and id
    [parseLinDatafromFile.py]
2024-10-07 fix break frame
